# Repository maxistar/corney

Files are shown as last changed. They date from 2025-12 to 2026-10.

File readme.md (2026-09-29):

# Corney - Corney Chocoflan and Classical Corne keyboard

Project site and firmware guide: https://projects.maxistar.me/corney/

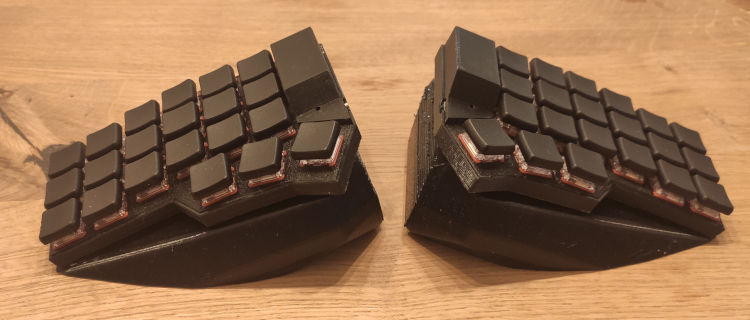
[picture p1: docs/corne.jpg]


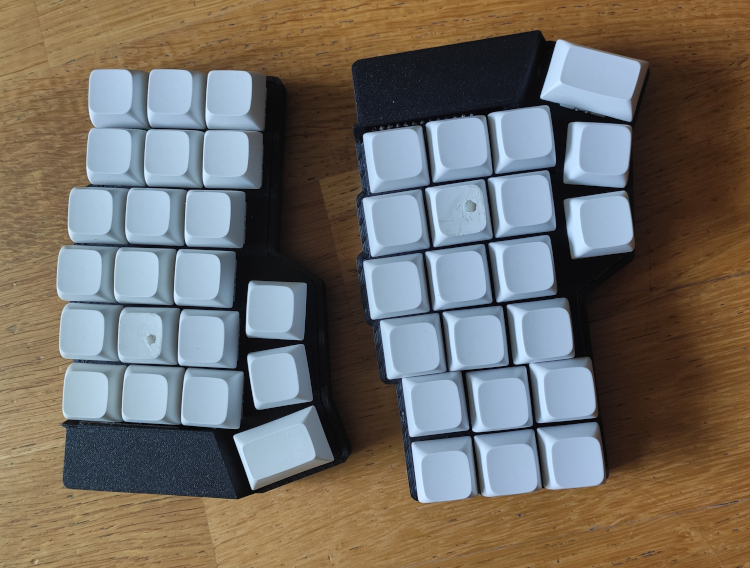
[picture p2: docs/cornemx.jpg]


- body remixed from this: https://www.printables.com/model/1020389-wireless-corne-chocoflan-minimal-keyboard-case

## Related Projects

- Dacty: https://github.com/maxistar/dacty

## Layout Helper

Use Keyboard Layout Helper to inspect and tune layers visually:
https://projects.maxistar.me/keyboard_helper/

## What's here

- `config/`: ZMK config for a split Corne on nice!nano (keymap, macros, Bluetooth bindings, west manifest).
- `body/`: printable/parametric case and plate models for the Chocoflan remix (scad, stl, step, 3mf).
- `build.yaml`: build matrix for CI (direct central, BLE halves, USB dongle, and reset firmware on `nice_nano_v2`).
- `website/`: static Astro project site and firmware selection guide. It can be built locally with
  `cd website && npm ci && npm run check && npm run build`; direct download links remain disabled
  until a versioned firmware release is physically accepted.
- `zephyr/module.yml`: declares the repo as a ZMK module, including the Corney shield root and
  the custom GATT features.
- `docs/gatt-layer-exposition.md`: UUIDs, data format, and build notes for the BLE layer
  characteristic.
- `docs/keyboard-helper-ble-v1.md`: implementation, security, queue, and build notes for the
  versioned Keyboard Helper event extension.
- `docs/dongle-oled-verification.md`: SSD1306 dongle wiring, resource delta, candidate hashes, and
  physical acceptance checklist.

## Clone

```bash
git clone https://github.com/maxistar/corney.git
cd corney
```

## Prerequisites

- Zephyr SDK and `west` already installed ([ZMK setup guide](https://zmk.dev/docs/development/setup))

## Build firmware (locally)

1. From the repo root, pull ZMK: `west init -l config && west update`.
2. Build the direct topology (outputs land in `build/<side>/zephyr/zmk.uf2`):
   - Left (enhanced): `west build -p -s zmk/app -d build/left -b nice_nano_v2 -- -DSHIELD=corney_left -DZMK_CONFIG=$PWD/config -DZMK_EXTRA_MODULES=$PWD -DCONFIG_ZMK_STUDIO=n -DCONFIG_ZMK_KEYBOARD_HELPER_EXTENSION=y`
   - Right: `west build -p -s zmk/app -d build/right -b nice_nano_v2 -- -DSHIELD=corney_right -DZMK_CONFIG=$PWD/config -DZMK_EXTRA_MODULES=$PWD`
3. Or build the dongle topology:
   - Left peripheral: `west build -p -s zmk/app -d build/left-peripheral -b nice_nano_v2 -- -DSHIELD=corney_left_peripheral -DZMK_CONFIG=$PWD/config -DZMK_EXTRA_MODULES=$PWD`
   - Right peripheral: use the same `corney_right` command and artifact as direct mode.
   - USB dongle: `west build -p -s zmk/app -d build/dongle -b nice_nano_v2 -- -DSHIELD=corney_dongle -DZMK_CONFIG=$PWD/config -DZMK_EXTRA_MODULES=$PWD -DCONFIG_ZMK_STUDIO=n -DCONFIG_ZMK_KEYBOARD_HELPER_EXTENSION=y`
4. Copy the corresponding UF2 to each nice!nano over USB bootloader.

`corney-left-enhanced` is the single supported left-central image for direct BLE operation. It
provides the ordinary keyboard HID behavior together with Keyboard Helper telemetry. Pair it with
the universal `corney-right` image, which supports right halves both with and without the physical
trackpad sensor.

The optional dongle topology uses `corney-left-peripheral` and the same `corney-right` image as two
BLE peripherals. `corney-usb-dongle` is their keyless central and sends keyboard and pointing HID
to the computer over USB. It drives a 128x64 SSD1306 status display over I2C and keeps the full
Keyboard Helper GATT service available over a separate encrypted BLE connection. Both host-facing
central images use the default name `Corney`.

ZMK Studio is intentionally disabled in the release firmware. The active layout is compiled from
`config/corney.keymap`; change that file and rebuild the left image to edit the layout. Previously
saved Studio overrides are not applied. The full Keyboard Helper event and diagnostics service
remains enabled.

## Build firmware with a custom Bluetooth name

The default Bluetooth device name is `Corney`. To override it, pass
`CONFIG_ZMK_KEYBOARD_NAME` when building a host-facing central.

Local build examples:

- Left (enhanced): `west build -p -s zmk/app -d build/left -b nice_nano_v2 -- -DSHIELD=corney_left -DZMK_CONFIG=$PWD/config -DZMK_EXTRA_MODULES=$PWD -DCONFIG_ZMK_STUDIO=n -DCONFIG_ZMK_KEYBOARD_HELPER_EXTENSION=y -DCONFIG_ZMK_KEYBOARD_NAME=\"CorneyMX\"`
- USB dongle: `west build -p -s zmk/app -d build/dongle -b nice_nano_v2 -- -DSHIELD=corney_dongle -DZMK_CONFIG=$PWD/config -DZMK_EXTRA_MODULES=$PWD -DCONFIG_ZMK_STUDIO=n -DCONFIG_ZMK_KEYBOARD_HELPER_EXTENSION=y -DCONFIG_ZMK_KEYBOARD_NAME=\"CorneyMX\"`
- Right: `west build -p -s zmk/app -d build/right -b nice_nano_v2 -- -DSHIELD=corney_right -DZMK_CONFIG=$PWD/config -DZMK_EXTRA_MODULES=$PWD`

Do not apply the custom name override to either peripheral image. Only the active central is
host-facing.

## Cirque trackpad

Both halves support an optional Cirque Pinnacle trackpad over their own Pro Micro I2C pins. Each
sensor uses address `0x2a`, does not connect its data-ready (`DR`) signal, and replaces rather than
shares the former OLED position. The same `corney-left-enhanced` and `corney-right` images support
four physical arrangements: no sensor, left only, right only, or one sensor on each half.

Because DR is absent, each controller with an installed sensor reads its status every 8 ms while
active. The left central consumes its local sensor directly. The right half forwards relative
movement, primary tap, and wheel packets over ZMK input-split to a separate central proxy listener.
Both paths produce ordinary USB or BLE HID mouse reports; Keyboard Helper remains central-owned and
does not carry pointer packets.

In dongle mode, both sensors are remote. The right endpoint retains input-split register `0`; the
left peripheral uses register `1`. The dongle has matching proxy listeners and no physical sensor
or matrix of its own. Button state is tracked per proxy. Because pinned ZMK v0.3.0 does not expose
the disconnected split connection's input-split identity, any split disconnect conservatively
clears retained remote button state; later events from a still-connected half continue normally.

The original left installation uses `invert-x`. The accepted right installation is rotated 180
degrees relative to its first prototype and uses `invert-y` without `invert-x`. These settings make
physical finger direction match cursor direction on each assembled half.

If either image boots without its optional sensor, initialization fails once and periodic polling
is not started on that controller. Matrix scanning, split operation, and an installed sensor on the
other half remain independent. The pinned ZMK baseline does not release input-split buttons
automatically on disconnect, so the left firmware tracks only right-proxy button state and performs
a bounded safety release when that split connection disappears. Local left buttons are not part of
that disconnect state.

Continuous polling costs additional battery power on every sensor-equipped half. During system
suspend the corresponding polling work stops; trackpad touch alone cannot wake that controller
without DR. Wake the left sensor with a left-local key and the right sensor with a right-local key or
another wake source on the same controller. The right pointing path also waits for split reconnect.

Movement, scrolling, and ordinary non-overlapping taps may be used from either sensor. The pinned
ZMK input listener does not source-count a simultaneous hold of the same mouse button from two
sensors, so that specific dual-button gesture is unsupported.

The explicitly named Choc printable entry points are
`body/Choc_Version/right_touchpad_body.scad` and
`body/Choc_Version/right_touchpad_cover.scad`; use
`body/Choc_Version/right_touchpad_assembly.scad` to inspect controller, reset, sensor, and wiring
clearances. Hardware acceptance for this topology is tracked in
`docs/right-peripheral-trackpad-verification.md`.

## USB dongle OLED

The `corney-usb-dongle` firmware selects one four-wire 128x64 SSD1306 module at I2C address `0x3c`
and displays a hybrid status screen. It preserves ZMK's standard output indicator at the upper
left, local dongle battery indicator at the upper right, and active layer at the lower left. One
compact row below the local battery shows both split-peripheral levels, for example `78% 56%`.

The two remote values follow persistent ZMK split-slot order but deliberately have no slot numbers
or left/right labels. Resetting bonds can reverse their order without changing the meaning of the
pair. An unavailable, not-yet-seen, or disconnected value is shown as `--`; pinned ZMK v0.3.0 also
uses zero as its disconnect sentinel, so a genuine remote `0%` is indistinguishable and is likewise
shown as unavailable. The standard dongle battery widget's power symbol reports USB presence; it
does not establish that an optional dongle cell is charging.

Wire the display only to the dedicated dongle nice!nano v2:

| SSD1306 pin | nice!nano v2 / Pro Micro pin |
| --- | --- |
| `VCC` | `3V3` |
| `GND` | `GND` |
| `SDA` | `D2` / `P0.17` |
| `SCL` | `D3` / `P0.20` |

Use a 3.3 V-compatible module; do not power an unknown panel from `RAW` or 5 V. The firmware expects
address `0x3c`, 128x64 geometry, and the orientation used by the tested module. The screen normally
blanks when ZMK enters idle and resumes after keyboard activity. The left and right halves do not
contain this OLED node—their separate I2C buses remain available for optional Cirque sensors.

Only the dongle needs to be reflashed for this display change. If the hybrid screen prevents normal
dongle operation, reflash
`.artifacts/show-corney-battery-levels-on-dongle/corney-usb-dongle.uf2`; the two peripheral images
and their split bonds do not otherwise change. Build and physical acceptance evidence is recorded
in `docs/dongle-hybrid-status-screen-verification.md`.

## CI/CD

GitHub Actions is the primary CI/CD pipeline. It runs portable protocol/metadata tests, native ZMK
integration tests, and builds `corney-left-enhanced`, `corney-left-peripheral`, `corney-right`,
`corney-usb-dongle`, and `settings-reset` firmware artifacts. A manual workflow run can override
the Bluetooth name for either central image only.

The GitLab CI configuration is retained as an equivalent alternative for a future GitLab mirror.
Local Bluetooth name overrides remain a CMake option so the right/peripheral image cannot
accidentally receive a host-facing name.

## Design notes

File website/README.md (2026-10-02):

# Corney website

Static Astro site for `https://projects.maxistar.me/corney/`.

```sh
npm ci
npm run check
npm run build
npm run dev
```

`src/data/firmware.js` is the public firmware source of truth. The checked-in record stays
`published: false` until a versioned GitHub Release is physically accepted and its five UF2 hashes
have been verified. Source code changes and temporary CI artifacts do not activate download links.

The production build validates routes, base paths, topology mappings, release claims and image
metadata. Public WebP photographs are sanitized derivatives of the repository's `docs/` originals.

## 3D models

The STL files served on the Models page are not committed here. `scripts/models-manifest.mjs` lists
each published `models/<group>/<file>.stl` and the file under `../body/` it comes from, and
`scripts/sync-models.mjs` copies them into the git-ignored `public/models/`. The sync runs
automatically before `npm run dev`, `check` and `build`; run `npm run sync-models` to do it by hand.
It fails on a missing source, a duplicate target, or an unlisted STL in `public/models/`. To publish a
new model, add it to the manifest and to `src/pages/models.astro`; a test checks that both agree. The
website workflow also runs when an STL under `body/` changes.

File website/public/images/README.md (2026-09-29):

# Corney website images

`corney-choc.webp` derives from `../../../docs/corne.jpg`; `corney-mx.webp` derives from
`../../../docs/cornemx.jpg`. Both source photographs belong to this repository. Public variants
were converted with ImageMagick `-auto-orient -strip -resize '1200x900>' -quality 82`, removing EXIF,
including location and camera information.

The alt descriptions live in `src/data/project.js`. There is currently no public photograph of the
dongle OLED or an installed trackpad; the site uses text and diagrams for those features.

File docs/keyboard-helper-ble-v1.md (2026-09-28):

# Keyboard Helper BLE extension v1

Corney's central (`corney_left`) firmware implements version 1.0 of the Keyboard Helper BLE
contract documented by the umbrella repository in `docs/zmk-ble-keyboard-contract-v1.md`. The
right/peripheral firmware preserves ordinary ZMK split position forwarding and never advertises
the host-facing service.

## Build modes

`CONFIG_ZMK_GATT_LAYER_EXPOSITION=y` keeps the legacy four-byte layer register available.
`CONFIG_ZMK_KEYBOARD_HELPER_EXTENSION=y` adds the capabilities and encrypted event stream. The
extension defaults off in Kconfig, while the supported `corney-left-enhanced` release artifact
enables it explicitly. The switches remain available for focused tests and local experiments, but
disabled and partial-extension configurations are not published release variants.

Optional capability switches are:

- `CONFIG_ZMK_KEYBOARD_HELPER_KEY_EVENTS`
- `CONFIG_ZMK_KEYBOARD_HELPER_COMBO_EVENTS`
- `CONFIG_ZMK_KEYBOARD_HELPER_LAYER_EVENTS`
- `CONFIG_ZMK_KEYBOARD_HELPER_DIAGNOSTICS`

The capabilities value is derived from these compiled options. Disabling one source clears only
its bit. Capability bit 3 and event type `0x04` are reserved and never emitted. Standard ZMK
Battery Service is the sole battery source in the maintained enhanced mode. Peripheral battery
fetching remains disabled and right-half battery support is deferred.

## Event capture

- Physical key events subscribe directly to central-observed `zmk_position_state_changed` and
  retain global positions `0..41` from both halves.
- Seven combo behaviors use a Corney wrapper that publishes stable combo ID and participants,
  then invokes the original ZMK binding unchanged.
- Legacy and enhanced layer reporting share the same authoritative cached highest layer.
- The custom stream contains no HID usage, keycode, Unicode, resolved behavior, or text.

`layout_corney.json` and `corney_macros.dtsi` carry the same combo IDs and positions. Run
`tests/run-host-tests.sh` to validate the mapping and the exact version 1 frame examples. Run
`tests/run-zmk-integration-tests.sh` to verify raw combo-participating positions, wrapper
press/release delegation, overlap resolution, non-text behavior, and absence of duplicate resolved
events in ZMK's native test runner.

## Queue and loss behavior

Event producers allocate one global sequence and perform a bounded, non-blocking append into
16-entry retained history. Each subscriber has its own cursor and retry state while notification
runs later in work context. A transient `-ENOMEM` or `-EAGAIN` result is retried no more than three
times, 10 ms apart, for the affected subscriber without delaying other ready subscribers.
Permanent failures, an exhausted retry budget, and history overwritten before a slow subscriber
consumes it produce a gap only in that subscriber's observed stream. Shared retention overflow
also schedules diagnostic code 1 when capacity becomes available.

## Concurrent subscribers and security

Capabilities remain readable before encryption. Enabling the event CCC requires an encrypted
connection. Every eligible connection receives an independent subscriber slot while configured
Bluetooth capacity remains available. Corney configures six simultaneous connections: one for
the right split peripheral and five host profiles, so at least two encrypted event subscribers
can coexist. `BT_ATT_ERR_INSUFFICIENT_RESOURCES` is reserved for actual subscriber/connection
capacity exhaustion and never transfers or cancels an existing subscription.

Telemetry subscription is independent of the active ZMK HID profile. Every subscriber receives a
targeted authoritative layer snapshot marked `STREAM_START | SNAPSHOT` before its future live
events. A subscriber joining, leaving, slowing down, or reconnecting does not reset or purge any
other subscriber's stream.

Firmware flashed before concurrent subscriber support is a development-only build and must be
reflashed. Protocol 1.0 UUIDs, capability bytes, and event frame layouts are unchanged; there is
no single-owner compatibility mode or version branch.

## Local verification

Run the portable tests:

```sh
tests/run-host-tests.sh
```

Build the enhanced central:

```sh
west build -p always -s zmk/app -d build/enhanced-left -b nice_nano_v2 -- \
  -DZMK_CONFIG="$PWD/config" \
  -DZMK_EXTRA_MODULES="$PWD" \
  -DSHIELD=corney_left \
  -DCONFIG_ZMK_KEYBOARD_HELPER_EXTENSION=y
```

Build `corney_right` without the extension override. A GATT database change can require clearing
old bonds or flashing the `settings_reset` image before pairing again.

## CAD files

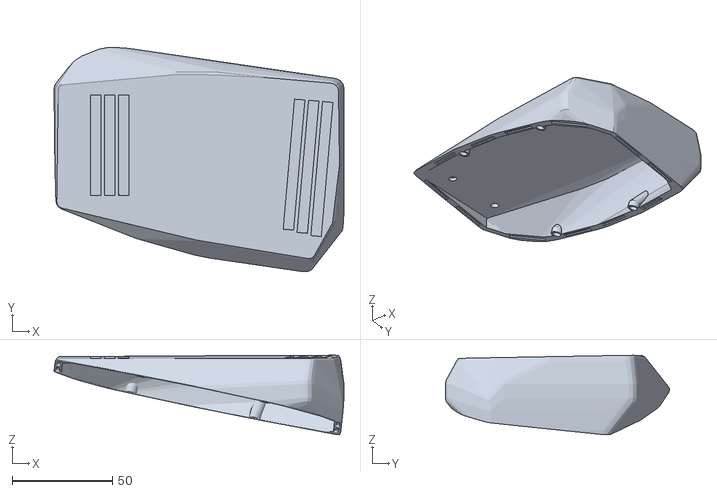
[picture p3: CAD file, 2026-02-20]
body/board_case.stl
144.3 x 111.7 x 39.6

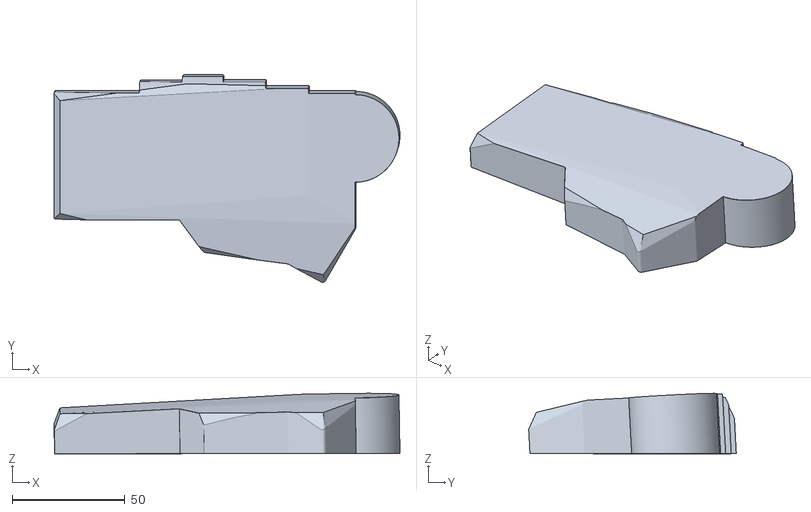
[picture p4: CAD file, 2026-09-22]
body/Choc_Version/internalshape.stl
153.6 x 92.2 x 26.9

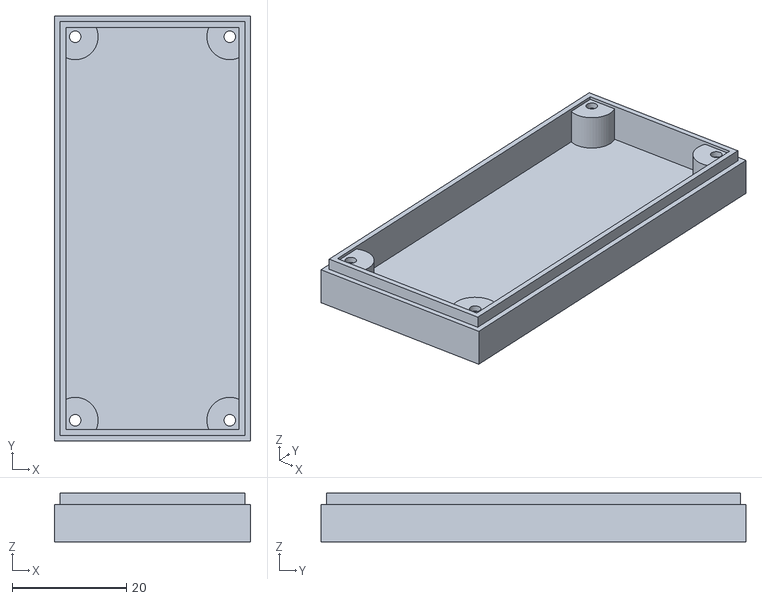
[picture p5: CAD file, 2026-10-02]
body/dongle/dongle_breadboard_bottom.stl
34.2 x 74.2 x 8.50

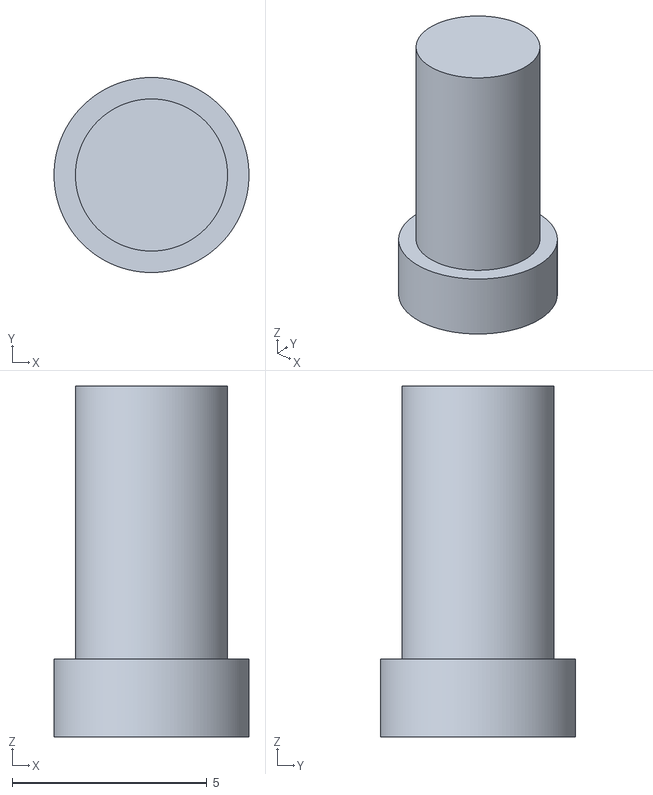
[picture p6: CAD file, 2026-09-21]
body/Choc_Version/reset_button_right.stl
5.00 x 5.00 x 9.00

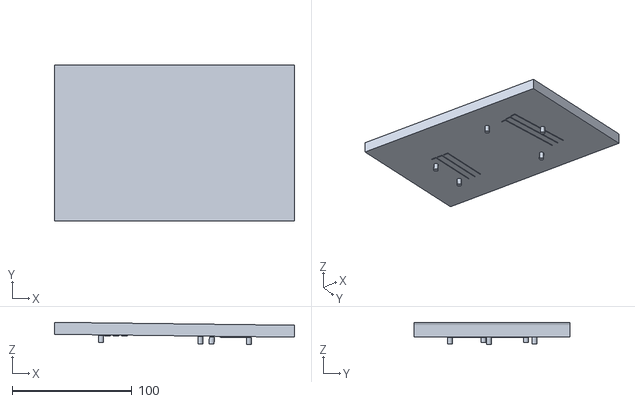
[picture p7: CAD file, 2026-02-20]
body/corne_shape_with_stands.stl
200.1 x 130.0 x 18.7

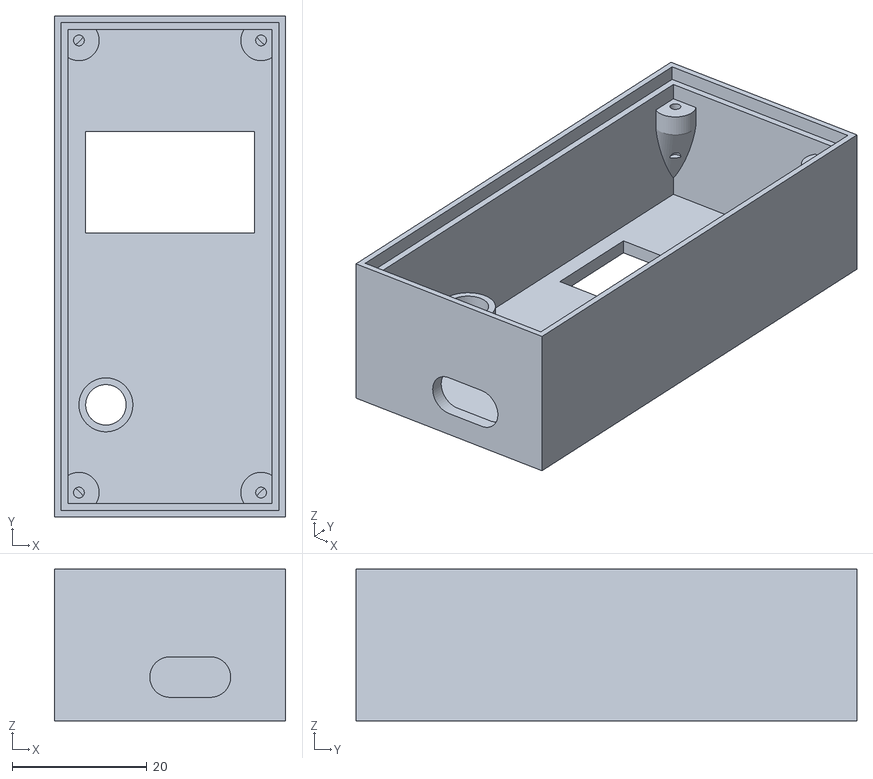
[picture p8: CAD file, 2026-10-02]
body/dongle/dongle_breadboard_upper.stl
34.2 x 74.2 x 22.5

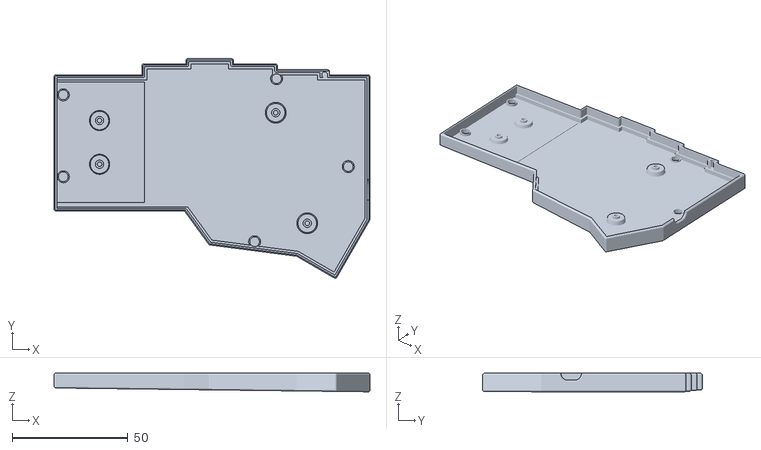
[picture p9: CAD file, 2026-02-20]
body/body_with_stands.stl
136.6 x 94.9 x 8.06

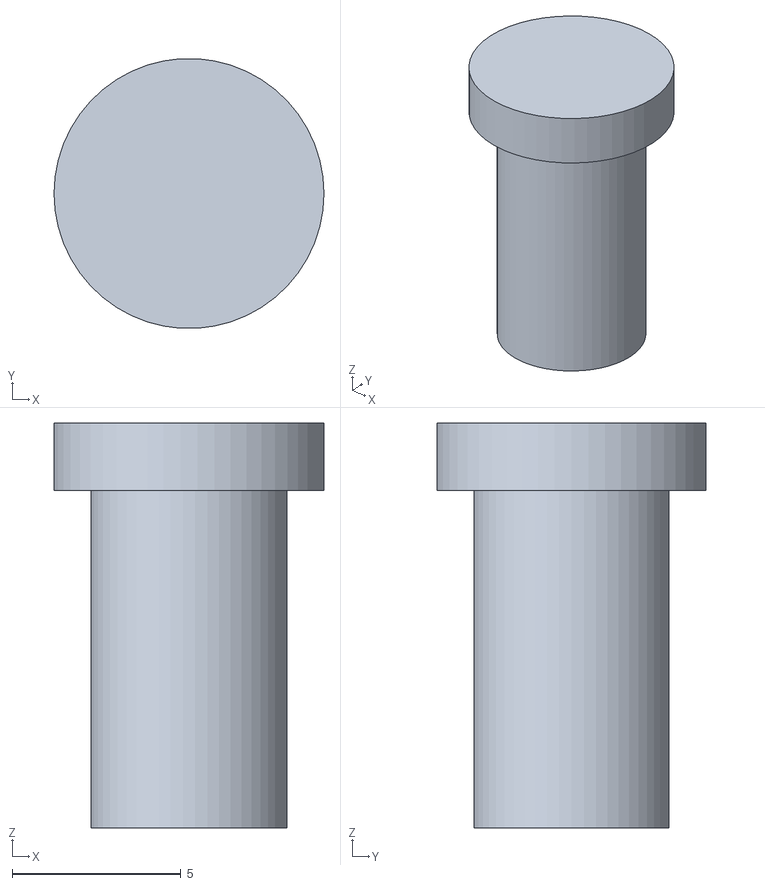
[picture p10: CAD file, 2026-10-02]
body/dongle/dongle_breadboard_button.stl
8.00 x 7.98 x 12.0

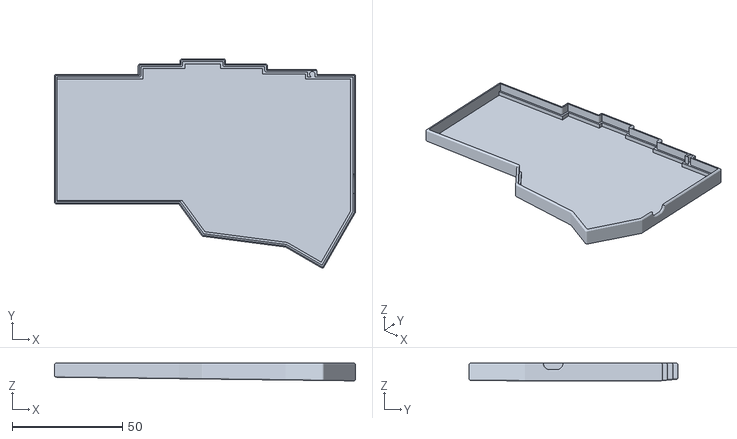
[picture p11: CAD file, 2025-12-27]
body/corne_chocoflan_basic.stl
136.6 x 94.9 x 8.06

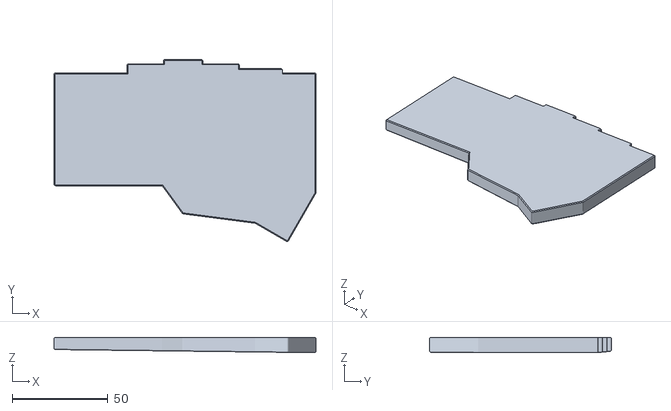
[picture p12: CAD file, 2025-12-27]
body/corne_shape.stl
136.6 x 94.9 x 8.06

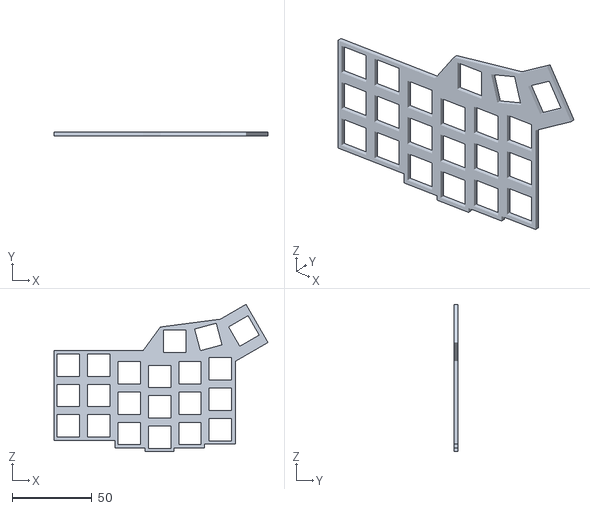
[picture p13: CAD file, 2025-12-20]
body/tbenen-plate.stl
133.8 x 2.20 x 92.2

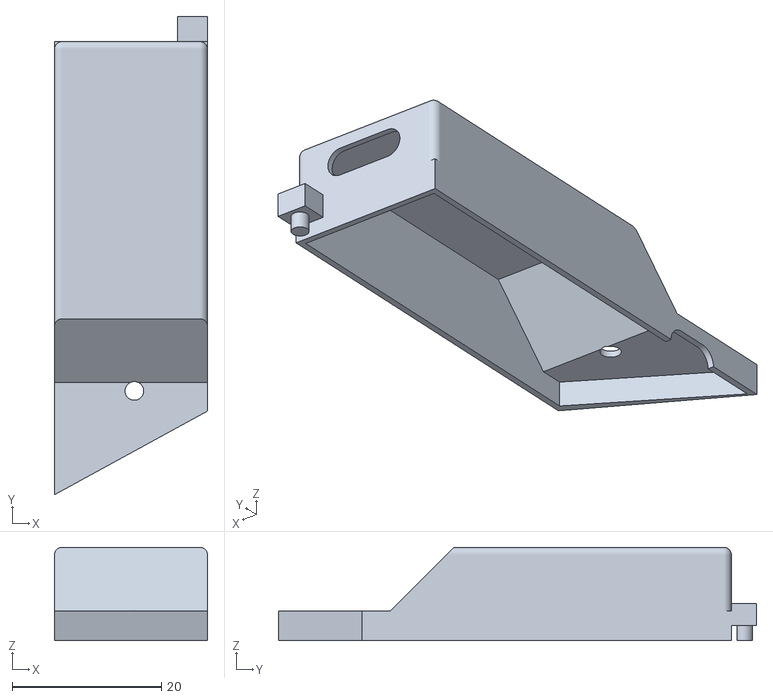
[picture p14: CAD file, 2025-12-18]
body/board_cover.stl
20.5 x 64.1 x 12.5

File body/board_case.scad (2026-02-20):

// case
/**
features todo: 
- [x] magnetic latch
- [x] placing keyboad on top of case as tilted support
- [x] magnetic fixation of the keyboard
- [x] additional pads fixation for the keyboard
- [x] rubber perimeter for better stability
- [ ] make maglet holders 3dprint friendly

*/

cut_angle = [-6, 13, 0];
magnet_radius = 4 / 2 + 0.1;
holder_thickness = 0.8;

module column3() {
  translate([32, 120, 14])
    cube([18, 18, 5], center=true);

  translate([32, 120 - 19, 14])
    cube([18, 18, 5], center=true);

  translate([32, 120 - 19 * 2, 14])
    cube([18, 18, 5], center=true);
}

module corne() {

  translate([17, 143, -8.5])
    import("body_with_stands.stl");

  translate([0, 136, -84])
    rotate([90, 0, 0])
      import("tbenen-plate.stl");

  translate([157, 129, 6])
    scale([-1, 1, 1])
      import("board_cover.stl");

  column3();

  translate([19, 0, 0])
    column3();

  translate([19 * 2, 3, 0])
    column3();

  translate([19 * 3, 6, 0])
    column3();

  translate([19 * 4, 3, 0])
    column3();

  translate([19 * 5, 0, 0])
    column3();

  translate([99, 66, 14])
    cube([18, 18, 5], center=true);

  translate([120, 63, 14])
    rotate([0, 0, -15])
      cube([18, 18, 5], center=true);

  translate([142, 60, 14])
    rotate([0, 0, -30])
      cube([18, 18, 5], center=true);
}

//corne();

module corne_centered() {
  translate([-90, -95, 0.1])
    corne();
}

module base_centered() {
  translate([-90, -95, 2])
    hull() {
      import("corne-chocoflan-case.stl");
    }
}

module cut_centered() {
  rotate([1, -1.0, 0])
    translate([-70, 48, -8.35])
      //hull() {
      import("corne_shape_with_stands.stl");
  //} 
}

module two_cornes() {
  corne_centered();

  rotate([0, 180, 0])
    scale([1, -1, 1])
      corne_centered();
}

module outline() {
  hull() {
    two_cornes();
  }
}

//two_cornes();

module shell() {
  difference() {
    minkowski() {
      outline();
      sphere(r=4.2);
    }

    minkowski() {
      outline();
      sphere(r=0.5);
    }
  }
  double_magnet_plane_half(magnet_radius + holder_thickness, 3);
}

module one_half() {

  difference() {
    shell();

    rotate(cut_angle)
      translate([0, 0, -50])
        cube([400, 400, 100], center=true);

    translate([5, 0, 20])
      cut_centered();

    double_angled_cuts();

    double_magnet_plane(magnet_radius, 2, 0.1);
  }

  intersection() {
    minkowski() {
      outline();
      sphere(r=4);
    }
    rotate(cut_angle) {
      print_helpers();
    }
  }
}

module print_helpers() {
  translate([30, 35.6, 2.7])
    hull() {
      cylinder(h=0.5, r=magnet_radius + holder_thickness, $fn=50);

      translate([3, 15, 20])
        cylinder(h=0.5, r=magnet_radius + holder_thickness, $fn=50);
    }

  translate([-30, -35.6, 2.7])
    hull() {
      cylinder(h=0.5, r=magnet_radius + holder_thickness, $fn=50);

      translate([0, -10, 10])
        cylinder(h=0.5, r=magnet_radius + holder_thickness, $fn=50);
    }

  translate([-33, 50, 2.7])
    hull() {
      cylinder(h=0.5, r=magnet_radius + holder_thickness, $fn=50);

      translate([0, 5, 10])
        cylinder(h=0.5, r=magnet_radius + holder_thickness, $fn=50);
    }

  translate([33, -50, 2.7])
    hull() {
      cylinder(h=0.5, r=magnet_radius + holder_thickness, $fn=50);

      translate([0, -5, 10])
        cylinder(h=0.5, r=magnet_radius + holder_thickness, $fn=50);
    }
}

one_half();

/*
translate([0, 0, -30])
  rotate([0, 180, 0])
    scale([1, -1, 1])
      one_half();
*/

module rubber_cuts() {
  translate([10, 44.2, 0])
    rotate([0, 0, -16])
      cube([20, 1.8, 1.8], center=true);

  translate([-19, 50.5, 0])
    rotate([0, 0, -8])
      cube([20, 1.8, 1.8], center=true);

  translate([-52.5, 49.5, 0])
    rotate([0, 0, 22.9])
      cube([20, 1.8, 1.8], center=true);

  translate([44, 33.5, 0])
    rotate([0, 0, -22])
      cube([20, 1.8, 1.8], center=true);

  translate([71, 6, 0])
    rotate([0, 0, -88])
      cube([20, 1.8, 1.8], center=true);

  translate([71, -22, 0])
    rotate([0, 0, -91])
      cube([20, 1.8, 1.8], center=true);
}

module angled_cuts() {
  rotate(cut_angle)
    rubber_cuts();
}

module double_angled_cuts() {
  angled_cuts();

  rotate([0, 180, 0])
    scale([1, -1, 1])
      angled_cuts();
}

module magnets_plane(radius, height, voffset) {

  translate([33, -49.9, voffset])
    cylinder(h=height * 2 + voffset * 2, r=radius, $fn=50, center=true);

  translate([30, 35.6, voffset])
    cylinder(h=height * 2 + voffset * 2, r=radius, $fn=50, center=true);
}

module angled_magnet_plane(radius, height, voffset) {
  rotate(cut_angle)
    magnets_plane(radius, height, voffset);
}

module double_magnet_plane(radius, height, voffset = 0) {
  angled_magnet_plane(radius, height, voffset);

  rotate([0, 180, 0])
    scale([1, -1, 1])
      angled_magnet_plane(radius, height, voffset);
}

module double_magnet_plane_half(radius, height, voffset = 0) {
  difference() {
    double_magnet_plane(radius=radius, height=height, voffset=voffset);

    rotate(cut_angle)
      translate([0, 0, -50])
        cube([400, 400, 100], center=true);
  }
}

module test_magnet() {
  difference() {
    cylinder(h=3, r=magnet_radius + holder_thickness, $fn=50);
    translate([0, 0, -0.1])
      cylinder(h=2 + 0.1, r=magnet_radius, $fn=50);
  }
}

//test_magnet();
//difference() {

//}

//double_angled_cuts();

//translate([5, 0, 20])
//  cut_centered();

//corne_centered();

//translate([0, 0, -40])
//  rotate([0, 180, 0])
//    scale([1, -1, 1])
//      corne_centered();

/*
difference() {

  translate([0, 0, -40])
    intersection() {
      shell();

      rotate([0, 20, 0])
        translate([0, 0, -50])
          cube([400, 400, 100], center=true);
    }

  translate([-15, 0, -60])
    rotate([0, 180, 0])
      scale([1, -1, 1])
        cut_centered(); 
}

*/
//import("corne_shape.stl");

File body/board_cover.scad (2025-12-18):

/**

- [x] sitting pins
- [ ] reset button cut
- [x] usb-c cut
- [x] power button cut
- [x] board space
- [x] bottom plate that fits into horizontal cut

*/

$fn = 50;

cover_width = 20.5;
cover_length_1 = 60.71;
cover_length_2 = 49.5;

cover_height = 12.5;
cover_height_min = 4;

wall_thickness = 0.8;
sittin_pin_radius = 2.5 / 2;

round_radius = 1.0;

module outer_shape_old() {
  linear_extrude(height=cover_height_min) {
    polygon([[0, 0], [0, -cover_length_1], [cover_width, -cover_length_2], [cover_width, 0]]);
  }

  difference() {
    linear_extrude(height=cover_height) {
      polygon([[0, 0], [0, -cover_length_1], [cover_width, -cover_length_2], [cover_width, 0]]);
    }

    translate([0, -60, 25])
      rotate([45, 0, 0])
        cube([100, 100, 50], center=true);
  }
}

module outer_shape() {

  wall_radius_bottom = 0;
  wall_radius_top = round_radius;

  linear_extrude(height=cover_height_min) {
    polygon([[wall_radius_bottom, -wall_radius_bottom], [wall_radius_bottom, wall_radius_bottom - cover_length_1], [cover_width - wall_radius_bottom, wall_radius_bottom - cover_length_2], [cover_width - wall_radius_bottom, -wall_radius_bottom]]);
  }

  difference() {
    minkowski() {
      linear_extrude(height=cover_height - wall_radius_top) {
        polygon([[wall_radius_top, -wall_radius_top], [wall_radius_top, wall_radius_top - cover_length_1], [cover_width - wall_radius_top, wall_radius_top - cover_length_2], [cover_width - wall_radius_top, -wall_radius_top]]);
      }
      sphere(r=wall_radius_top);
    }

    translate([0, -60, 25])
      rotate([45, 0, 0])
        cube([100, 100, 50], center=true);

    translate([0, 0, -50])
      cube([200, 200, 100], center=true);
  }
}

module inner_shape() {
  difference() {
    translate([0, 0, -wall_thickness]) {
      linear_extrude(height=cover_height) {
        polygon([[wall_thickness, -wall_thickness], [wall_thickness, wall_thickness - cover_length_1], [cover_width - wall_thickness, wall_thickness - cover_length_2], [cover_width - wall_thickness, -wall_thickness]]);
      }
    }

    translate([0, -60, 25 - wall_thickness])
      rotate([45, 0, 0])
        cube([100, 100, 50], center=true);
  }

  translate([0, 0, -wall_thickness]) {
    linear_extrude(height=cover_height_min) {
      polygon([[wall_thickness, -wall_thickness], [wall_thickness, wall_thickness - cover_length_1], [cover_width - wall_thickness, wall_thickness - cover_length_2], [cover_width - wall_thickness, -wall_thickness]]);
    }
  }
}

module cuts() {

  // Power button cut
  translate([-5, -50.5, 0]) {
    rotate([0, 90, 0]) {
      hull() {
        cylinder(h=9, r=2.0, center=false);
        translate([0, 4, 0])
          cylinder(h=9, r=2.0, center=false);
      }
    }
  }

  // USB-C cut
  translate([14, -6, 8.6]) {
    rotate([0, 90, 90]) {
      hull() {
        cylinder(h=10, r=1.8, center=false);
        translate([0, 7, 0])
          cylinder(h=9, r=1.8, center=false);
      }
    }
  }

  translate([cover_width - 9.8, -cover_length_2 + 2.7, wall_thickness])
    cylinder(h=cover_height_min, r=sittin_pin_radius, center=false);
}

difference() {
  outer_shape();
  inner_shape();
  cuts();
}
/*
translate([3.6, -cover_length_1 + 5.7, -wall_thickness])
  cylinder(h=cover_height_min, r=sittin_pin_radius, center=false);

translate([cover_width - 4.5, -cover_length_2 + 3, -wall_thickness])
  cylinder(h=cover_height_min, r=sittin_pin_radius, center=false);
*/
translate([cover_width - 2.0, +1.8, /*-wall_thickness*/ 0])
  cylinder(h=cover_height_min, r=sittin_pin_radius - 0.2, center=false);

translate([16.5, 0, 2]) {
  cube([4, 3.4, 3]);
}

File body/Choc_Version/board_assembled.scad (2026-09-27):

use <body_thin.scad>
use <board_cover.scad>
use <reset_button_right.scad>
use <_buttons_low_profile.scad>
use <_auxiliary.scad>


module panelbuttons(fullheight = false, simplified = false) {
  if (simplified) {
    body_simplified();
  } else {
    body();
    panel();
  }


  buttons();

  /*
  translate([58, 13, 20]) {
    nice_nano_placeholder();
  }
  */

  if (simplified) {
    translate([0, 0, 15.5]) {
      cover_simplified();
      resetButtonSmall();
    }
  } else {
    translate([0, 0, 15.5]) {
      cover();
      resetButtonSmall();
    }
  }

  
}

module panelbuttonsmoved(fullheight = false, simplified=false) {
  translate([0, 0, -4]) {
    panelbuttons(fullheight=fullheight, simplified = simplified);
  }
}

//panel();
panelbuttonsmoved(simplified = true);

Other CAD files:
body/ImprovedCorne.FCStd
body/corne-chocoflan-case.step
body/Choc_Version/board_assembled_touchpad.scad
body/Choc_Version/_auxiliary.scad
body/Choc_Version/_buttons_low_profile.scad
body/Choc_Version/board_case.scad
body/Choc_Version/board_cover.scad
body/Choc_Version/board_cover_touchpad.scad
body/Choc_Version/body_thin.scad
body/Choc_Version/body_thin_touchpad.scad
body/Choc_Version/face_panel.scad
body/Choc_Version/reset_button.scad
body/Choc_Version/reset_button_right.scad
body/Choc_Version/right_touchpad_assembly.scad
body/Choc_Version/right_touchpad_body.scad
body/Choc_Version/right_touchpad_cover.scad
body/Choc_Version/travel_case_side_by_side.scad
body/Choc_Version/twokeyboards.scad
body/Choc_Version/twokeyboards_side_by_side.scad
body/MX_Version/Outline.scad
body/MX_Version/Outline_thin.scad
body/MX_Version/board_assembled.scad
body/MX_Version/board_case.scad
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

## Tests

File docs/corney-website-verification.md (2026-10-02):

# Corney website verification

# Website status

The public site is deployed at https://projects.maxistar.me/corney/ and the visual presentation was
accepted by the project owner. Home, Firmware, Build and Guide are available under `/corney/`. It uses the
two existing assembly photographs as sanitized WebP assets and keeps firmware downloads unpublished
until a versioned, physically accepted compatibility set is selected.

## Local checks

- `website/npm run check`: Astro diagnostics have 0 errors, 0 warnings and 0 hints; firmware data
  tests pass.
- `website/npm run build`: four static routes build; the post-build validator passes route, asset,
  base-path, topology, release-state, image-alt and WebP metadata checks.
- `website/npm audit --audit-level=low`: 0 vulnerabilities after upgrading to Astro 7 and using
  self-hosted fonts.
- `tests/run-host-tests.sh`: existing Corney host checks and release packaging tests pass.
- The project owner confirmed that the GitHub Actions tests pass after the host-test fix.
- A local package smoke test using the five previously accepted UF2 files and their generated
  Kconfig outputs produced a checksummed ZIP with exactly five images plus `SHA256SUMS`.
- In a browser, all four routes had no horizontal overflow or broken images at 320 and 1440 CSS
  pixels. The first Tab focuses the visible skip link. No remote page resources loaded; primary
  content rendered from static HTML. The unpublished firmware page exposed no release asset links.
- Primary repo, Choc and MX source, keymap, contributor documents and Keyboard Helper URLs returned
  HTTP 200 during local verification.
- Representative text contrast ratios: muted copy 9.55:1, accent on page background 15.10:1,
  warning text 10.74:1 and button text 14.60:1.
- The deployed Home, Firmware, Build and Guide routes were smoke-tested in a browser at 320 and
  1440 CSS pixels: no page-level horizontal overflow, broken images, missing image alternatives,
  or internal links escaping `/corney/` were found.

## Prototype dongle case

The Models page has a "USB dongle case (prototype)" set with three STL files copied from
`body/dongle/` (source last changed in `e1ed106`, byte-identical at copy time): bottom shell, upper
shell and reset button. The Build page has a prototype block (30 x 70 mm breadboard design basis,
adjustable OpenSCAD parameters, screen cut-out still being refined) and the Guide dongle section links
to it as optional. The Home page is unchanged.

- `website/npm run check` and `npm run build`: 0 errors, 4 data tests pass, the post-build validator
  passes with five routes.
- Local preview: the dongle set loads its STL (HTTP 200), the viewer renders the shell with no console
  errors, and the Build page has no horizontal overflow at 320 CSS pixels.

## Models built from sources

The 3D models are no longer committed under `website/public/models/`. `website/scripts/models-manifest.mjs`
maps each published model to its file in `body/`, and `scripts/sync-models.mjs` copies them before
`dev`, `check` and `build`; the output directory is git-ignored. The website workflow also runs when an
STL under `body/` changes.

- Before untracking, the generated directory was byte-identical to the 16 committed copies and the 3
  untracked dongle copies.
- From an empty `public/models/`, `npm run check` (8 tests pass) and `npm run build` pass, and the
  resulting `dist/` is identical to the previous build output, including all 19 STL files.
- Fault injection: an unlisted STL, a missing source (the build aborts before Astro runs) and a
  duplicate target each fail with a message naming the entry; the mapping was restored afterwards.

## Firmware release still pending

- Choose the first release version and accepted source revision.
- Create the tagged candidate, verify its published assets, and perform physical acceptance of both
  firmware topologies and settings reset.
- Update the checked-in release record only after the candidate is physically accepted.

The website deployment does not constitute acceptance or publication of a firmware release.

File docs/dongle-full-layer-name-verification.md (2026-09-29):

# Corney Dongle Full Layer Name Verification

Date: 2026-09-29

## Change

The dongle's custom status screen now reads the active layer's complete ZMK display name and draws
it beside a stationary keyboard symbol in the bottom row. The label uses all 112 pixels to the
right of the 14-pixel symbol and 2-pixel gap. LVGL circular scrolling is enabled on that label; text
that fits the row stays static, while longer names move through the available window at 20 pixels
per second. The configured LVGL default is 49 pixels per second, so the new rate is about 2.45
times slower (the nearest whole-pixel speed to exactly 2.5 times slower).

The existing output, local dongle battery, and two remote battery indicators retain their positions
and data paths. The implementation replaces only the dongle screen's stock layer widget, whose
14-byte formatting buffer truncated names before LVGL received them.

## Automated verification

- [x] Corney host tests pass, including source/layout checks for the ZMK active-layer API, layer
  event subscription, full-width name label, circular overflow mode, fixed keyboard symbol,
  reduced scroll speed, and dongle-only source selection.
- [x] Generated configuration and topology checks pass for all five Corney release targets.
- [x] Only `corney-usb-dongle` selects the custom screen; its stock layer widget is disabled. The
  other four retained release UF2 hashes are unchanged from the accepted battery-screen build.
- [x] The dongle target builds on pinned ZMK v0.3.0.

## Resource usage

| Dongle image | FLASH | RAM | UF2 size |
| --- | ---: | ---: | ---: |
| Accepted battery-screen image | 328,564 B | 68,436 B | 657,408 B |
| Full layer name candidate at 20 px/s | 345,800 B | 68,596 B | 691,712 B |
| Change | +17,236 B | +160 B | +34,304 B |

The candidate uses 42.64% of the 792 KiB application flash region and 26.17% of the 256 KiB RAM
region.

## Candidate artifact

The candidate and its generated configuration and devicetree are retained under
`.artifacts/show-full-layer-name-on-corney-dongle/`.

| Artifact | Size | SHA-256 |
| --- | ---: | --- |
| `corney-usb-dongle.uf2` | 691712 bytes | `37c69459b891b583ffd7e9dd11c3bde6a99d83de31c606c4ed522dafdb3a64a9` |

Rollback to the accepted battery-screen-only image at
`.artifacts/show-corney-battery-levels-on-dongle/corney-usb-dongle.uf2` (657408 bytes,
SHA-256 `675c8a22f8a7ce96112b784710e4675035262cc9e60d813c6a68d91fafdf674a`). Only the dongle needs
flashing; no half firmware or BLE bond change is expected.

## Physical acceptance

- [x] Confirmed a short name remains stationary and a long name, such as `MAC: Characters and
  Navigation Russian`, scrolls fully and legibly next to the keyboard symbol.
- [x] Confirmed the 20 px/s scroll speed is comfortable; layer changes, output and battery rows,
  display idle blanking/wake, and existing
  dongle typing, pointing, BLE reconnect, and Keyboard Helper behavior remain usable.

Physical acceptance was user-confirmed on 2026-09-29, including the reduced scrolling speed.

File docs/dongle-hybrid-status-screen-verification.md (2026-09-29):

# Corney Dongle Hybrid Status Screen Verification

Date: 2026-09-29

## Scope

The `corney-usb-dongle` custom compositor restores ZMK's standard output, local-battery, and
active-layer widgets at their built-in screen anchors and adds one identity-neutral remote battery
row below the local dongle indicator:

```text
┌────────────────────────┐
│ output          dongle │
│             78%   56%  │
│                        │
│ active layer           │
└────────────────────────┘
```

The two fields retain split-source-index order internally but carry no visible slot number or
left/right claim. Reversing slot assignment after a bond reset therefore does not change the user
meaning. Available values render as bounded `N%`; unavailable values render as `--`.

## Data and presentation boundaries

- ZMK's standard widgets exclusively own output/endpoint state, local dongle battery/USB state, and
  the highest active layer.
- The Corney listener subscribes only to `zmk_peripheral_battery_state_changed` and initializes from
  both retained split battery levels.
- The auxiliary BAS proxy remains disabled. Remote values remain display-local and do not change
  Keyboard Helper capabilities or the dongle's standard Battery Service meaning.
- Pinned ZMK v0.3.0 reports remote disconnect as level zero, so both disconnect and a genuine remote
  `0%` render as `--`.
- The standard local battery widget's lightning/power symbol indicates USB presence; it is not
  evidence that an optional dongle battery is installed or charging.
- The remote row uses Montserrat 12 in a 65-pixel right-aligned area at `y=20..34`. The unkerned
  pinned-font upper bound for `100% 100%` is 65 pixels. The stock top region uses Montserrat 16 with
  an 18-pixel line height, and the bottom layer region uses the 15-pixel small font.

## Automated verification

- [x] Portable host tests cover initial `-- --`, independent updates, bounded values,
  disconnect-zero handling, reversed slot arrival, and `100% 100%`.
- [x] `tests/verify_dongle_display_layout.py` derives glyph advances and line heights from the pinned
  Montserrat sources and verifies the remote row's horizontal and vertical bounds.
- [x] All four native ZMK integration fixtures pass: combo wrapper ordinary/overlap, both-half event
  sources, and input-split pointing/disconnect cleanup.
- [x] All five `nice_nano_v2` release targets build on ZMK commit
  `edf5c0814fd3ea202e43aad2d68fd32e882a518c` (v0.3.0 pin).
- [x] Generated configuration/devicetree verification passes for every target. Only the dongle
  selects the custom compositor, three standard widgets, Montserrat 12/16, and remote battery
  fetching; built-in status and auxiliary BAS proxy remain disabled.
- [x] The direct central, both peripherals, and settings-reset UF2 hashes exactly match the accepted
  preceding battery-screen release.

## Resource change

| Dongle build | FLASH | RAM | UF2 size |
| --- | ---: | ---: | ---: |
| Accepted compact battery screen | 328,564 B | 68,436 B | 657,408 B |
| Hybrid stock-geometry screen | 345,860 B | 68,612 B | 692,224 B |
| Change | +17,296 B | +176 B | +34,816 B |

The hybrid build uses 42.65% of the 792 KiB application flash region and 26.17% of the 256 KiB RAM
region. Relative to the earlier built-in OLED screen it adds 1,888 B FLASH, 160 B RAM, and 4,096 B
of UF2 output while also presenting both remote levels.

## Candidate artifacts

Candidate UF2 files and matching generated `.config` and `zephyr.dts` evidence are stored under
`.artifacts/refine-corney-dongle-status-screen/`.

| Artifact | Size | SHA-256 |
| --- | ---: | --- |
| `corney-left-enhanced.uf2` | 496128 bytes | `7aba0ccd18874ecdf3829aa3a69ed6db863d40a87026ecf3969bad7ef5ce696c` |
| `corney-left-peripheral.uf2` | 355840 bytes | `51069e75b64495508b1ecaff860dee4f62a85456fa7d382ec870c45f81f2396b` |
| `corney-right.uf2` | 355840 bytes | `f7b7a74931fbe5ddcad91d0888dd13a3f5954c8e8d1eb1066bdf61b1280a6185` |
| `corney-usb-dongle.uf2` | 692224 bytes | `0eee7cc882c368aa87ac47aa947d5561093a931f55f81ae276ecb1ac3e04c932` |
| `settings-reset.uf2` | 92672 bytes | `fd3072a56b359a56b08ad0c010b77ebe516846fc59ca21aa5c1059518a082d60` |

## Flash and rollback

Flash only
`.artifacts/refine-corney-dongle-status-screen/corney-usb-dongle.uf2`. Existing half images and BLE
bonds remain compatible and should not be replaced or reset.

If rollback is required, flash
`.artifacts/show-corney-battery-levels-on-dongle/corney-usb-dongle.uf2`. No half reflash is required.

## Physical acceptance

- [x] Confirm the output indicator at upper left, local battery at upper right, unlabeled remote pair
  beneath it, and active layer at lower left are legible and do not visibly overlap.
- [x] Change active layers and endpoint state and confirm the standard widgets update independently.
- [x] Power-cycle each half independently and confirm one field changes to `--` and later recovers
  while the other remains available.
- [x] Confirm idle blanking/wake, USB HID, keys from both halves, available pointing paths,
  disconnect cleanup, and Keyboard Helper retain their accepted behavior.
- [x] Rollback was not required because physical acceptance passed; the documented dongle-only
  rollback artifact remains available.

Physical acceptance was user-confirmed on 2026-09-29. The hybrid screen was reported to look good,
and no layout, input, reconnect, wake, or integration regression was reported.

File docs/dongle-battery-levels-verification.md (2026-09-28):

# Corney Dongle Battery Levels Verification

Date: 2026-09-28

## Scope

The `corney-usb-dongle` custom status screen presents three independent power sources on the
existing 128x64 SSD1306:

```text
Half 1   78%
Half 2   64%
Dongle   42% USB
```

`Half 1` and `Half 2` are ZMK peripheral source slots, not permanent left/right identities. The
labels therefore remain valid if the halves bond in another order. A disconnected or not-yet-seen
slot is shown as `--`.

Only the dongle firmware changes. The direct central, both peripheral images, and settings-reset
remain byte-identical to the accepted `add-corney-dongle-oled` artifacts. The existing SSD1306
devicetree, orientation, idle blanking, and keyboard-activity wake configuration are unchanged.

## Data boundaries and limitations

- The dongle fetches Battery Service values from both split peripherals with
  `CONFIG_ZMK_SPLIT_BLE_CENTRAL_BATTERY_LEVEL_FETCHING`.
- The auxiliary BAS proxy remains disabled. Battery values are display-local and do not add a
  Keyboard Helper capability or event.
- In pinned ZMK v0.3.0, a peripheral disconnect is reported with level zero. The display therefore
  treats remote `0%` as unavailable and shows `--`; a genuinely empty remote battery cannot be
  distinguished from a disconnected one.
- `Dongle` uses the local ZMK Battery Service state. `USB` means USB power is present and does not
  claim that a battery is charging. `BAT` means USB power is absent.
- Until a battery is installed on the dongle, accuracy of its battery-backed percentage remains a
  deferred physical check.

## Automated verification

- [x] Portable host tests cover initial unavailable slots, independent updates, bounds,
  disconnect-zero handling, local level changes, and USB/BAT formatting.
- [x] Native ZMK integration tests pass for combo delegation, both-half events, input-split
  pointing, and disconnect cleanup.
- [x] All five `nice_nano_v2` release targets build on ZMK commit
  `edf5c0814fd3ea202e43aad2d68fd32e882a518c` (v0.3.0 pin).
- [x] Generated configurations and devicetrees pass `tests/verify_cirque_build.py` for every target.
- [x] Only the dongle selects the custom screen and two-slot battery fetching. The built-in status
  screen and auxiliary BAS proxy are disabled, and the other four targets contain none of the new
  screen code.

## Resource change

| Dongle build | FLASH | RAM | UF2 size |
| --- | ---: | ---: | ---: |
| Accepted built-in OLED screen | 343,972 B | 68,452 B | 688,128 B |
| Custom battery screen | 328,564 B | 68,436 B | 657,408 B |
| Change | -15,408 B | -16 B | -30,720 B |

The custom build uses 40.51% of the 792 KiB application flash region and 26.11% of the 256 KiB
RAM region.

## Candidate artifacts

Candidate UF2 files and matching generated `.config` and `zephyr.dts` evidence are stored under
`.artifacts/show-corney-battery-levels-on-dongle/`.

| Artifact | Size | SHA-256 |
| --- | ---: | --- |
| `corney-left-enhanced.uf2` | 496128 bytes | `7aba0ccd18874ecdf3829aa3a69ed6db863d40a87026ecf3969bad7ef5ce696c` |
| `corney-left-peripheral.uf2` | 355840 bytes | `51069e75b64495508b1ecaff860dee4f62a85456fa7d382ec870c45f81f2396b` |
| `corney-right.uf2` | 355840 bytes | `f7b7a74931fbe5ddcad91d0888dd13a3f5954c8e8d1eb1066bdf61b1280a6185` |
| `corney-usb-dongle.uf2` | 657408 bytes | `675c8a22f8a7ce96112b784710e4675035262cc9e60d813c6a68d91fafdf674a` |
| `settings-reset.uf2` | 92672 bytes | `fd3072a56b359a56b08ad0c010b77ebe516846fc59ca21aa5c1059518a082d60` |

The four non-dongle hashes exactly match the accepted preceding OLED candidate. Only
`corney-usb-dongle` changed.

## Flash and rollback

For physical acceptance, flash only the new `corney-usb-dongle.uf2`. Existing half images and BLE
bonds should remain usable; no half reflash or re-pairing is expected.

If rollback is needed, flash
`.artifacts/add-corney-dongle-oled/corney-usb-dongle.uf2` on the dongle. The halves do not need to
be reflashed.

## Physical acceptance

- [x] Confirmed legible `Half 1`, `Half 2`, and `Dongle` values plus the USB marker.
- [x] Power-cycled each half independently and confirmed `--` then recovered level without breaking
  keys, pointing, USB HID, or disconnect cleanup.
- [x] Confirmed display idle blanking/wake and unchanged Keyboard Helper behavior.
- [x] Accepted dongle local data flow and USB indication; percentage accuracy remains pending until
  a dongle battery is installed.

Physical acceptance was user-confirmed on 2026-09-28. No connection or update-delay limitation was
reported. The pending dongle battery-backed percentage is an explicitly accepted hardware gap, not
a failure of the current USB-powered configuration.

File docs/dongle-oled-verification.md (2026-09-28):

# Corney USB Dongle OLED Verification

Date: 2026-09-28

## Scope

`corney-usb-dongle` now selects one four-wire 128x64 SSD1306 at I2C address `0x3c` and renders
ZMK's built-in status screen. The display is isolated to the USB-powered dongle. The direct central,
left peripheral, right peripheral, and settings-reset targets remain display-free; their accepted
matrix, optional Cirque, split, pointing, and Keyboard Helper roles do not change.

The configuration was adapted from the hardware-tested `my-zmk-test` overlay. Corney's pinned
Zephyr binding supports the geometry, orientation, precharge, and 100 ms ready delay used here but
does not support the newer `use-internal-iref` property, so that property is intentionally absent.

## Wiring

Use a 3.3 V-compatible four-pin I2C SSD1306 module:

| SSD1306 pin | Dongle nice!nano v2 / Pro Micro pin |
| --- | --- |
| `VCC` | `3V3` |
| `GND` | `GND` |
| `SDA` | `D2` / `P0.17` |
| `SCL` | `D3` / `P0.20` |

The expected address is `0x3c`. Do not use `RAW` or 5 V unless the exact module has separately been
verified to accept that supply. Neither keyboard half is rewired for this change.

## Automated verification

- [x] Portable host tests pass, including the exact five-artifact release matrix.
- [x] Native ZMK integration tests pass for combo delegation, both-half events, and input-split
  pointing/disconnect recovery.
- [x] All five `nice_nano_v2` release targets build on pinned ZMK v0.3.0.
- [x] Generated configurations and devicetrees pass `tests/verify_cirque_build.py` for every target.
- [x] The dongle resolves I2C, SSD1306, Zephyr/ZMK display support, built-in status screen, and
  one-bit LVGL output while retaining USB, BLE split central, both pointing proxies, disconnect
  safety, and the complete Keyboard Helper extension.
- [x] The dongle generated devicetree selects exactly one 128x64 SSD1306 at `0x3c`, contains no
  physical Cirque or GPIO matrix, and the other four targets contain no dongle display.

## Resource change

Linker memory usage and UF2 size are compared with the accepted display-free dongle whose UF2 hash
is `d8577d60330acd78af3eca2b65f170738285cfd2bf35ec7b99f1e02ebd1144f0`.

| Dongle build | FLASH | RAM | UF2 size |
| --- | ---: | ---: | ---: |
| Display-free baseline | 242,704 B | 62,132 B | 485,888 B |
| Built-in OLED status screen | 343,972 B | 68,452 B | 688,128 B |
| Change | +101,268 B | +6,320 B | +202,240 B |

The display-enabled build uses 42.41% of the 792 KiB application flash region and 26.11% of the
256 KiB RAM region.

## Candidate artifacts

Candidate UF2 files and matching generated `.config` and `zephyr.dts` evidence are stored under
`.artifacts/add-corney-dongle-oled/`.

| Artifact | Size | SHA-256 |
| --- | ---: | --- |
| `corney-left-enhanced.uf2` | 496128 bytes | `7aba0ccd18874ecdf3829aa3a69ed6db863d40a87026ecf3969bad7ef5ce696c` |
| `corney-left-peripheral.uf2` | 355840 bytes | `51069e75b64495508b1ecaff860dee4f62a85456fa7d382ec870c45f81f2396b` |
| `corney-right.uf2` | 355840 bytes | `f7b7a74931fbe5ddcad91d0888dd13a3f5954c8e8d1eb1066bdf61b1280a6185` |
| `corney-usb-dongle.uf2` | 688128 bytes | `c5e6b8606ff9a921da79c93d1a68e95cdd628b0ed9faf7e98dc5f0cf0ee877ad` |
| `settings-reset.uf2` | 92672 bytes | `fd3072a56b359a56b08ad0c010b77ebe516846fc59ca21aa5c1059518a082d60` |

The four non-dongle artifacts are byte-identical to the accepted preceding dongle-topology
candidate. Only `corney-usb-dongle` changed.

## Physical acceptance

- [x] Wired the compatible SSD1306 and flashed only the new `corney-usb-dongle` candidate.
- [x] Confirmed legible built-in ZMK status content in the expected orientation after boot.
- [x] Confirmed idle blanking and wake after keyboard activity.
- [x] Confirmed USB enumeration, typing from both halves, available pointing paths, Keyboard Helper,
  and independent half reconnect while the display is active.
- [x] The candidate passed, so rollback was not required. The preceding display-free dongle UF2
  remains available without reflashing either half.

Physical acceptance was user-confirmed on 2026-09-28: all requested manual tests passed and the
display looked as expected. The display changes only the central image; neither peripheral was
reflashed for this check.

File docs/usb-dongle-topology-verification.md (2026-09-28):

# Corney USB Dongle Topology Verification

Date: 2026-09-28

## Firmware roles

- `corney-left-enhanced`: existing direct central with local left Cirque, right input-split proxy,
  USB/BLE HID, and Keyboard Helper BLE service.
- `corney-left-peripheral`: BLE left half with matrix scanning and optional Cirque forwarded through
  input-split register `1`.
- `corney-right`: universal BLE right half with optional Cirque forwarded through the retained
  input-split register `0`.
- `corney-usb-dongle`: keyless central with two BLE peripheral slots, two pointing proxies, USB
  HID, and Keyboard Helper BLE service.
- `settings-reset`: bond-reset utility.

Both central targets use the default device name `Corney`. ZMK Studio remains disabled. Keyboard
Helper continues to use encrypted BLE GATT even while the dongle sends HID to the computer over
USB. The dongle does not report the battery level of either half.

## Entering dongle mode

Changing the central invalidates the existing split bonds. Do not try to reuse bonds from direct
mode.

1. Flash `settings-reset` to the future dongle, left half, and right half; allow each device to boot.
2. Flash `corney-usb-dongle` to the dongle.
3. Flash `corney-left-peripheral` to the left half.
4. Flash the unchanged `corney-right` artifact to the right half.
5. Power the dongle from the computer over USB and power both halves. Allow both split bonds to be
   established before testing.

## Returning to direct mode

1. Flash `settings-reset` to the left and right halves; reset the dongle too before its next use.
2. Flash `corney-left-enhanced` to the left half.
3. Flash the same `corney-right` artifact to the right half.
4. Pair the `Corney` central to the intended BLE hosts again.

## Automated acceptance

- [x] Host tests pass, including exact five-artifact matrix checks.
- [x] Native ZMK integration tests pass, including two input-split registers, independent retained
  button state, bounded cleanup, and continued post-cleanup input.
- [x] All five `nice_nano_v2` targets build on pinned ZMK `v0.3.0`.
- [x] Generated configurations and devicetrees pass `tests/verify_cirque_build.py`.
- [x] Candidate UF2 files, hashes, and generated configuration evidence are retained.

The candidate files are stored under `.artifacts/add-corney-usb-dongle-topology/`; matching
resolved `.config` and `zephyr.dts` files are retained in its `config/` and `devicetree/`
subdirectories.

| Artifact | Size | SHA-256 |
| --- | ---: | --- |
| `corney-left-enhanced.uf2` | 496128 bytes | `7aba0ccd18874ecdf3829aa3a69ed6db863d40a87026ecf3969bad7ef5ce696c` |
| `corney-left-peripheral.uf2` | 355840 bytes | `51069e75b64495508b1ecaff860dee4f62a85456fa7d382ec870c45f81f2396b` |
| `corney-right.uf2` | 355840 bytes | `f7b7a74931fbe5ddcad91d0888dd13a3f5954c8e8d1eb1066bdf61b1280a6185` |
| `corney-usb-dongle.uf2` | 485888 bytes | `d8577d60330acd78af3eca2b65f170738285cfd2bf35ec7b99f1e02ebd1144f0` |
| `settings-reset.uf2` | 92672 bytes | `fd3072a56b359a56b08ad0c010b77ebe516846fc59ca21aa5c1059518a082d60` |

## Physical acceptance

- [x] Keys, combos, and layers from each half work independently and together over dongle USB HID.
- [x] Each half can be power-cycled without disabling the other, reconnects, and leaves no stuck
  key or pointing button.
- [x] Every available left/right Cirque path is checked for movement, orientation, tap, supported
  wheel input, key-driven idle resume, reconnect, and sensorless operation.
- [x] An encrypted BLE client observes Keyboard Helper capabilities and representative key, combo,
  layer, reconnect, and two-subscriber behavior while USB HID is active.
- [ ] The direct `corney-left-enhanced` plus `corney-right` topology still passes its accepted
  no-dongle regression checks after resetting bonds. This check was explicitly deferred by the
  user on 2026-09-28 to avoid reflashing the currently accepted dongle topology.
- [x] Simultaneous operation of two installed compatible Cirque sensors is explicitly recorded as
  **pending**, not passed: a two-sensor physical assembly is not currently available.

On 2026-09-28 the user flashed all three dongle-topology devices and confirmed operation of the
dongle and all existing functions. The direct-topology rollback check remains outstanding and was
explicitly deferred because it requires resetting bonds and reflashing the left half from
`corney-left-peripheral` to `corney-left-enhanced` (followed by re-pairing); the current confirmation
covered the three-device dongle topology.

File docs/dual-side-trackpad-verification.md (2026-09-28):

# Dual-side Cirque Trackpad Verification

Date: 2026-09-28

## Firmware topology

The release pair supports an optional Cirque Pinnacle at address `0x2a` on either or both halves:

- `corney-left-enhanced` polls a local sensor with `invert-x` and sends its events through a
  dedicated local ZMK input listener. It also retains the separate input-split proxy listener for
  the right sensor.
- `corney-right` retains the accepted polling device, `invert-y` orientation, and input-split
  endpoint.
- `settings-reset` contains neither Cirque device nor pointing listener.

The left/central release build uses the default Bluetooth name `Corney`; no
`CONFIG_ZMK_KEYBOARD_NAME` override was supplied. ZMK Studio remains disabled and the complete
Keyboard Helper capability set remains enabled.

## Automated verification

- `tests/run-host-tests.sh`: pass, including packet, wheel, button, per-side orientation, BLE
  metadata, and exact release-matrix checks.
- `tests/run-zmk-integration-tests.sh`: pass for all four fixtures, including input-split movement,
  wheel, button, disconnect release, reconnect, and synchronization events.
- `tests/verify_cirque_build.py`: pass for generated `corney_left`, `corney_right`, and
  `settings_reset` configurations and devicetrees.
- All three `nice_nano_v2` release targets build successfully without adding an artifact.

## Central resource change

Relative to the accepted Studio-free central from `remove-zmk-studio-from-corney-firmware`:

| Central build | FLASH | RAM | UF2 size |
| --- | ---: | ---: | ---: |
| Studio-free, right sensor only | 243,864 B | 59,836 B | 487,936 B |
| Optional left and right sensors | 247,916 B | 60,036 B | 496,128 B |
| Change | +4,052 B | +200 B | +8,192 B |

## Candidate artifacts

The default-name release candidates are stored under
`.artifacts/restore-corney-left-trackpad/`:

| Artifact | Size | SHA-256 |
| --- | ---: | --- |
| `corney-left-enhanced.uf2` | 496128 bytes | `fedd853f9ae453237221466a126c01cd26dcd3ffa5e9861498a8bbda25adb838` |
| `corney-right.uf2` | 355840 bytes | `f7b7a74931fbe5ddcad91d0888dd13a3f5954c8e8d1eb1066bdf61b1280a6185` |
| `settings-reset.uf2` | 92672 bytes | `fd3072a56b359a56b08ad0c010b77ebe516846fc59ca21aa5c1059518a082d60` |

The right and settings-reset images are byte-identical to the preceding accepted release; only the
left central changed.

## Physical acceptance

User-confirmed on 2026-09-28:

- On the available left-sensor keyboard, X/Y direction, scrolling, primary tap, USB and BLE
  pointing, key-driven idle resume, ordinary typing, combos, layers, and Keyboard Helper work as
  expected.
- The retained right-sensor path, split reconnect, right-local-key resume, right-source release,
  and sensorless behavior remain confirmed by the preceding right-peripheral acceptance and were
  reported as working as expected for the remaining scenarios.
- No new battery, responsiveness, or throughput limitation was observed during the reported tests.

A keyboard with physical sensors installed on both halves was not available. Dual-sensor
coexistence and simultaneous relative input on one split pair therefore remain unverified hardware
scenarios even though both generated paths compile together in the central image. This limitation
was explicitly accepted for archiving.

Movement, scrolling, and non-overlapping taps are supported from either sensor. Simultaneously
holding the same logical mouse button from both sensors is outside the accepted contract because
the pinned ZMK input listener does not source-count button ownership; this unsupported gesture was
not physically tested.

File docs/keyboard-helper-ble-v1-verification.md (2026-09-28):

# Keyboard Helper BLE v1 verification record

> Historical evidence: the Studio-enabled central measurements below predate
> `remove-zmk-studio-from-corney-firmware`. The current release central disables ZMK Studio while
> retaining the full Keyboard Helper service; the recorded protocol results remain applicable.

This record intentionally contains no captured typing content, addresses, credentials, or bonding
material.

## Reproducible build evidence

- Date: 2026-08-31
- ZMK revision: `v0.2.1` (`241ff39556b3685c9344c4c22fd9a655af8eb3ba`)
- Original requested board string: `nice_nano@2.0.0` (later found to resolve to the v1 board
  definition on this Zephyr 3.5 baseline; superseded by the corrected v2 artifacts below)
- Protocol: `1.0`
- Host tests: passed
- ZMK native event/combo integration tests: passed
- Position metadata: 42 unique global positions
- Combo metadata: IDs `1..7`, complete and consistent between layout and devicetree

### Hosted CI status

The first GitHub Actions native-test run failed before executing a test because the unanchored
`.gitignore` entry `zmk` also excluded `tests/zmk` from the repository. The rule is now anchored to
the root checkout as `/zmk`, and the integration fixtures are included. The next run reached the
fixtures but invoked `west build` outside the isolated west workspace, so all cases failed before
compilation. The workflow now runs the checkout's test script with `$base_dir` as its working
directory and enables verbose build output. All three cases pass locally in the same
`zmkfirmware/zmk-build-arm:stable` container. The subsequent hosted GitHub Actions rerun completed
successfully, including host tests, native integration tests, and the firmware build matrix.

| Build | Extension configuration | FLASH | RAM | Result |
| --- | --- | ---: | ---: | --- |
| Central legacy | extension disabled | 237,656 B | 59,660 B | pass |
| Central enhanced | release configuration, including ZMK Studio RPC | 268,904 B | 87,538 B | pass |
| Central extension-only | all extension capabilities, ZMK Studio disabled | 240,512 B | 60,276 B | pass |
| Central minimal | extension enabled, optional event sources disabled | 239,392 B | 60,276 B | pass |
| Peripheral/right | no host-facing extension | 172,616 B | 33,884 B | pass |
| Settings reset | utility image | 46,188 B | 11,552 B | pass |

Extension-only versus legacy central delta is 2,856 B FLASH and 616 B RAM. The release-enhanced
image also includes ZMK Studio RPC, so its 31,248 B FLASH and 27,878 B RAM delta is not attributable
to the BLE extension alone. All keyboard variants retain ZMK's standard Battery Service; capability
bit 3 is masked clear, custom event type `0x04` is reserved, and split-central peripheral battery
fetching remains disabled.

### Concurrent-transport platform evidence (2026-09-01)

- The supported central configuration explicitly sets `CONFIG_BT_MAX_CONN=6` and
  `CONFIG_BT_MAX_PAIRED=6`: five ZMK host profiles plus the right split peripheral. The transport
  has a build assertion requiring `CONFIG_BT_MAX_CONN` to cover configured split-central
  peripherals plus at least two host subscribers.
- ZMK `v0.2.1` pins Zephyr `v3.5.0+zmk-fixes`. In that revision, targeted
  `bt_gatt_notify(conn, ...)` checks the selected connection's CCC state and copies notification
  data into a Bluetooth buffer before returning. The worker's per-attempt stack frame therefore
  remains valid without a completion callback; a successful return means the caller-owned bytes
  have already been copied, not that the radio transmission has completed.
- A disconnect callback removes only the matching registry slot and releases its retained
  `bt_conn` reference. Managed CCC restoration after encryption is idempotent, so restoring one
  persisted subscription does not reset another subscriber.
- The retained event history remains 16 entries and stores each encoded live frame once. The
  subscriber registry is fixed at build time from `CONFIG_BT_MAX_CONN`; there is no heap allocation
  and no single-owner compatibility branch.

The concurrent transport was then rebuilt in the same official ZMK container and pinned workspace:

| Post-change build | FLASH | RAM | Delta from pre-change counterpart | Result |
| --- | ---: | ---: | ---: | --- |
| Central enhanced | 270,264 B | 87,906 B | +1,360 B FLASH, +368 B RAM | pass |
| Peripheral/right | 172,616 B | 33,884 B | unchanged | pass |

The resolved central `.config` contains `CONFIG_BT_MAX_CONN=6`,
`CONFIG_BT_MAX_PAIRED=6`, `CONFIG_ZMK_SPLIT_BLE_CENTRAL_PERIPHERALS=1`, and a 16-entry retained
history. The central uses 33.32% of its 792 KiB application FLASH region and 33.53% of its 256 KiB
RAM region. The pinned native ZMK event/combo integration suite also passes with the concurrent
sources.

## ZMK v0.3.0 upgrade evidence (2026-09-05)

- Manifest revision: `v0.3.0` (`edf5c0814fd3ea202e43aad2d68fd32e882a518c`)
- Imported Zephyr revision: `v3.5.0+zmk-fixes` (`dacab4875df72109b96cc8977547a0dc04875bcd`)
- Board: `nice_nano_v2` (legacy Zephyr 3.5 identifier, not HWMv2 syntax)
- Protocol: unchanged at `1.0`
- Formatting and host tests: passed
- ZMK native event/combo integration tests: all three cases passed
- Firmware source adaptations: none required

All targets declared in `build.yaml` were built from the updated west workspace with Zephyr SDK
0.16.8. The Studio-enabled target additionally used an isolated Python 3.12 environment containing
`protobuf`, `grpcio-tools`, and `setuptools<81`; the setuptools upper bound preserves the
`pkg_resources` API used by the pinned nanopb generator.

| Build | Extension configuration | FLASH | RAM | UF2 size | Result |
| --- | --- | ---: | ---: | ---: | --- |
| Central legacy | extension disabled | 238,568 B | 58,620 B | 477,184 B | pass |
| Central enhanced | release configuration, including ZMK Studio RPC | 271,296 B | 86,874 B | 542,720 B | pass |
| Central minimal | extension enabled, optional event sources disabled | 241,112 B | 59,604 B | 482,304 B | pass |
| Peripheral/right | no host-facing extension | 173,320 B | 33,900 B | 347,136 B | pass |
| Settings reset | utility image | 46,188 B | 11,552 B | 92,672 B | pass |

Every corrected artifact resolves `CONFIG_BOARD_NICE_NANO_V2=y`; all normal keyboard images also
resolve `CONFIG_ZMK_BATTERY_NRF_VDDH=y`. The enhanced central resolves
`CONFIG_BT_MAX_CONN=6`, `CONFIG_BT_MAX_PAIRED=6`,
`CONFIG_ZMK_SPLIT_BLE_CENTRAL_PERIPHERALS=1`, `CONFIG_ZMK_STUDIO=y`, and a 16-entry Keyboard
Helper history. This retains five host-profile slots alongside the split peripheral and satisfies
the build assertion reserving capacity for at least two concurrent host subscribers. The
`v0.3.0` update did not change BLE UUIDs, capability bits, frame layouts, keymap metadata, or the
legacy layer-control contract.

### v0.3.0 hardware acceptance status

The initial `v0.3.0` images were flashed to both halves and ordinary keyboard behavior was reported
to work as expected, but BLE Battery Level read 0%. Inspection showed those images had resolved
`nice_nano@2.0.0` to the pin-compatible v1 board definition and selected its absent ADC voltage
divider. The previous 100% reading was also not valid: ZMK `v0.2.1` left the Battery Service's
default value unchanged when the sampled state remained zero, while `v0.3.0` synchronizes zero to
the service. These preliminary images are superseded and are not accepted artifacts.

The corrected `nice_nano_v2` images select the controller's VDDH sensor and passed the full
automated matrix. Matching corrected images were then flashed to both halves and manually accepted:

- ordinary typing, both-half input, split reconnect, configured combos, and layers worked as
  expected;
- pointing movement and scrolling worked over USB and BLE, including profile switching;
- ZMK Studio connected and exposed the keymap;
- an encrypted generic BLE client successfully exercised legacy layer read/write/notify, Keyboard
  Helper discovery and capabilities, stream-start snapshot, representative key/combo/layer events,
  disconnect, and resubscription;
- existing bonds and settings survived the update, so the settings-reset image was not required;
- standard BLE Battery Level reported a plausible nonzero value independently of Keyboard Helper
  telemetry.

This confirms that selecting the v2 VDDH sensor fixes the invalid zero reading and that the accepted
ZMK `v0.3.0` images preserve the required hardware behavior.

## Cirque polling build evidence (2026-09-06)

The left/central shield now contains the I2C-only Cirque Pinnacle polling driver. The sensor is at
address `0x2a`, has no DR connection, and is polled every 8 ms while the central is active. Host
tests cover status filtering, malformed packet rejection, signed relative-axis boundaries, wheel
decoding, explicit X-axis orientation inversion, and primary-button press/hold/release transitions.
The left shield enables X inversion so physical right/left finger movement maps to the same cursor
direction while Y remains unchanged. The existing BLE metadata/transport
host tests and all three native ZMK event/combo integration tests also pass.

Every target declared in `build.yaml` was rebuilt from the pinned ZMK `v0.3.0` workspace:

| Build | FLASH | RAM | UF2 size | Result |
| --- | ---: | ---: | ---: | --- |
| Central legacy | 242,592 B | 58,836 B | 485,376 B | pass |
| Central enhanced with Studio | 275,668 B | 87,162 B | 551,424 B | pass |
| Central minimal | 245,136 B | 59,820 B | 490,496 B | pass |
| Peripheral/right | 173,320 B | 33,900 B | 347,136 B | pass |
| Settings reset | 46,188 B | 11,552 B | 92,672 B | pass |

Generated configuration and devicetree output contain `CONFIG_I2C=y`,
`CONFIG_INPUT_CORNEY_PINNACLE_POLLING=y`, and `glidepoint@2a` only for central targets. The right
and settings-reset artifacts contain none of them. Hardware movement, tap, suspend/resume, and
battery-impact checks remain pending until matching images are flashed.

The first hardware movement check found the installed sensor's X direction reversed while Y was
correct. The rebuilt central images enable the tested `invert-x` transform; same-direction
right/left cursor movement was confirmed after flashing the corrected left image.
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

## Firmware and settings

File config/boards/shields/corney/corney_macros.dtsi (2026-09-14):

// layers
#define DEFAULT 0
#define DEFAULT_LINUX 1
#define DEFAULT_LINUX_SHIFT 2
#define DEFAULT_LINUX_ALT 3
#define DEFAULT_MAC  4
#define DEFAULT_MAC_SHIFT  5
#define DEFAULT_MAC_ALT  6
#define DEFAULT_ANDROID 7
#define RUSSIAN 8
#define RUSSIAN_MAC 9
#define RUSSIAN_MAC_SHIFT 10
#define RUSSIAN_ALT 11
#define RUSSIAN_MAC_ALT 12
#define FUNC 13
#define CHARS 14
#define CHARS_DE 15
#define CHARS_MAC 16
#define CHARS_MAC_RUS 17
#define MOUSE_LAYER 18


/ {
    behaviors {
        kh_combo_esc: kh_combo_esc {
            compatible = "corney,behavior-combo-telemetry";
            #binding-cells = <0>;
            combo-id = <1>;
            key-positions = <1 2>;
            bindings = <&kp ESC>;
        };
        kh_combo_enter: kh_combo_enter {
            compatible = "corney,behavior-combo-telemetry";
            #binding-cells = <0>;
            combo-id = <2>;
            key-positions = <15 16>;
            bindings = <&kp RET>;
        };
        kh_combo_left_enter: kh_combo_left_enter {
            compatible = "corney,behavior-combo-telemetry";
            #binding-cells = <0>;
            combo-id = <3>;
            key-positions = <19 20>;
            bindings = <&kp RET>;
        };
        kh_combo_delete: kh_combo_delete {
            compatible = "corney,behavior-combo-telemetry";
            #binding-cells = <0>;
            combo-id = <4>;
            key-positions = <27 28>;
            bindings = <&kp BSPC>;
        };
        kh_combo_left_delete: kh_combo_left_delete {
            compatible = "corney,behavior-combo-telemetry";
            #binding-cells = <0>;
            combo-id = <5>;
            key-positions = <31 32>;
            bindings = <&kp BSPC>;
        };
        kh_combo_mouse_layer: kh_combo_mouse_layer {
            compatible = "corney,behavior-combo-telemetry";
            #binding-cells = <0>;
            combo-id = <6>;
            key-positions = <40 41>;
            bindings = <&tog MOUSE_LAYER>;
        };
        kh_combo_mouse_layer_left: kh_combo_mouse_layer_left {
            compatible = "corney,behavior-combo-telemetry";
            #binding-cells = <0>;
            combo-id = <7>;
            key-positions = <36 37>;
            bindings = <&tog MOUSE_LAYER>;
        };
    };

    combos {
        compatible = "zmk,combos";
        combo_esc {
            timeout-ms = <50>;
            key-positions = <1 2>;
            bindings = <&kh_combo_esc>;
        };
        combo_enter {
            timeout-ms = <50>;
            key-positions = <15 16>;
            bindings = <&kh_combo_enter>;
        };
        combo_left_enter {
            timeout-ms = <50>;
            key-positions = <19 20>;
            bindings = <&kh_combo_left_enter>;
        };
        combo_delete {
            timeout-ms = <50>;
            key-positions = <27 28>;
            bindings = <&kh_combo_delete>;
        };
        combo_left_delete {
            timeout-ms = <50>;
            key-positions = <31 32>;
            bindings = <&kh_combo_left_delete>;
        };
        combo_mouse_layer {
            timeout-ms = <50>;
            key-positions = <40 41>;
            bindings = <&kh_combo_mouse_layer>;
        };
        combo_mouse_layer_left {
            timeout-ms = <50>;
            key-positions = <36 37>;
            bindings = <&kh_combo_mouse_layer_left>;
        };
    };
};

/ {
    macros {

        to_linux: to_linux {
          compatible = "zmk,behavior-macro";
          #binding-cells = <0>;
          bindings = <&to DEFAULT_LINUX>,
                     <&bt BT_SEL 0>;
        };

        to_mac: to_mac {
          compatible = "zmk,behavior-macro";
          #binding-cells = <0>;
          bindings = <&to DEFAULT_MAC>,
                     <&bt BT_SEL 1>;
        };

        to_mac2: to_mac2 {
          compatible = "zmk,behavior-macro";
          #binding-cells = <0>;
          bindings = <&to DEFAULT_MAC>,
                     <&bt BT_SEL 2>;
        };

        to_mac3: to_mac3 {
          compatible = "zmk,behavior-macro";
          #binding-cells = <0>;
          bindings = <&to DEFAULT_MAC>,
                     <&bt BT_SEL 3>;
        };

        to_android: to_android {
          compatible = "zmk,behavior-macro";
          #binding-cells = <0>;
          bindings = <&to DEFAULT_ANDROID>,
                     <&bt BT_SEL 2>;
        };

        cycle_lang_de: cycle_lang_de {
            compatible = "zmk,behavior-macro";
            #binding-cells = <0>;
            bindings
                = <&to DEFAULT_LINUX>,
                  <&kp CAPS>;
        };

        cycle_android: cycle_android {
            compatible = "zmk,behavior-macro";
            #binding-cells = <0>;
            bindings
                = <&to RUSSIAN>,
                  <&sk LCTRL &kp SPACE>;
        };

        cycle_android_de: cycle_android_de {
            compatible = "zmk,behavior-macro";
            #binding-cells = <0>;
            bindings
                = <&to DEFAULT_ANDROID>,
                  <&sk LCTRL &kp SPACE>;
        };

        cycle_mac_de: cycle_mac_de {
            compatible = "zmk,behavior-macro";
            #binding-cells = <0>;
            bindings
                = <&to DEFAULT_MAC>,
                  <&kp CAPS>;
        };

        cycle_lang_ru: cycle_lang_ru {
            compatible = "zmk,behavior-macro";
            #binding-cells = <0>;
            bindings
                = <&to RUSSIAN>,
                  <&kp CAPS>;
        };

        cycle_mac_ru: cycle_mac_ru {
            compatible = "zmk,behavior-macro";
            #binding-cells = <0>;
            bindings
                = <&to RUSSIAN_MAC>,
                  <&kp CAPS>;
        };

        cycle_lang_en: cycle_lang_en {
            compatible = "zmk,behavior-macro";
            #binding-cells = <0>;
            bindings
                = <&to DEFAULT>,
                  <&kp CAPS>;
        };

        altgr_q_for_at: altgr_q_for_at {
            compatible = "zmk,behavior-macro";
            #binding-cells = <0>;
            bindings = <&sk RALT &kp Q>;
        };
        
        altgr_e: altgr_e {
            compatible = "zmk,behavior-macro";
            #binding-cells = <0>;
            bindings = <&sk RALT &kp L>;
        };

        altgr_l_for_at: altgr_l_for_at {
            compatible = "zmk,behavior-macro";
            #binding-cells = <0>;
            bindings = <&sk RALT &kp L>;
        };
        altgr_MINUS: altgr_MINUS {
            compatible = "zmk,behavior-macro";
            #binding-cells = <0>;
            bindings = <&sk RALT &kp MINUS>;
        };

        altgr_N5: altgr_N5 {
            compatible = "zmk,behavior-macro";
            #binding-cells = <0>;
            bindings = <&sk RALT &kp N5>;
        };

        altgr_N6: altgr_N6 {
            compatible = "zmk,behavior-macro";
            #binding-cells = <0>;
            bindings = <&sk RALT &kp N6>;
        };


        altgr_N7: altgr_N7 {
            compatible = "zmk,behavior-macro";
            #binding-cells = <0>;
            bindings = <&sk RALT &kp N7>;
        };
        
        altgr_shift_N7: altgr_shift_N7 {
            compatible = "zmk,behavior-macro";
            #binding-cells = <0>;
            bindings = <&sk RALT &sk LSHIFT &kp N7>;
        };

        altgr_N8: altgr_N8 {
            compatible = "zmk,behavior-macro";
            #binding-cells = <0>;
            bindings = <&sk RALT &kp N8>;
        };

        altgr_N9: altgr_N9 {
            compatible = "zmk,behavior-macro";
            #binding-cells = <0>;
            bindings = <&sk RALT &kp N9>;
        };

        altgr_N0: altgr_N0 {
            compatible = "zmk,behavior-macro";
            #binding-cells = <0>;
            bindings = <&sk RALT &kp N0>;
        };

        altgr_RBKT: altgr_RBKT
        {
            compatible = "zmk,behavior-macro";
            #binding-cells = <0>;
            bindings = <&sk RALT &kp RBKT>;
        };

        altgr_LT: altgr_LT
        {
            compatible = "zmk,behavior-macro";
            #binding-cells = <0>;
            bindings = <&sk RALT &kp LT>;
        };

        altgr_NUBACK: altgr_NUBACK {
            compatible = "zmk,behavior-macro";
            #binding-cells = <0>;
            bindings = <&sk RALT &kp NON_US_BACKSLASH>;
        };

        altgr_N: altgr_N
        {
            compatible = "zmk,behavior-macro";
            #binding-cells = <0>;
            bindings = <&sk RALT &kp N>;
        };
                
        alt_TAB: altgr_TAB
        {
            compatible = "zmk,behavior-macro";
            #binding-cells = <0>;
            bindings = <&sk RALT &kp TAB>;
        };
        

        //======================================

        shift_LALT: shift_LALT {
            compatible = "zmk,behavior-macro";
            #binding-cells = <0>;
            bindings = <&sk LSHIFT &kp LALT>;
        };
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

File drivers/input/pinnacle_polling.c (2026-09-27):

/*
 * Copyright (c) 2024 The ZMK Contributors
 * Copyright (c) 2026 Maxim Korenyugin
 *
 * SPDX-License-Identifier: MIT
 *
 * Register access and initialization are adapted from
 * https://github.com/petejohanson/cirque-input-module.
 */

#define DT_DRV_COMPAT corney_cirque_pinnacle_polling

#include <errno.h>
#include <stdbool.h>
#include <stdint.h>

#include <zephyr/device.h>
#include <zephyr/devicetree.h>
#include <zephyr/drivers/i2c.h>
#include <zephyr/dt-bindings/input/input-event-codes.h>
#include <zephyr/input/input.h>
#include <zephyr/kernel.h>
#include <zephyr/logging/log.h>
#include <zephyr/pm/device.h>
#include <zephyr/sys/util.h>

#include <corney/pinnacle_packet.h>

LOG_MODULE_REGISTER(corney_pinnacle, CONFIG_INPUT_LOG_LEVEL);

#define PINNACLE_READ_MASK 0xA0U
#define PINNACLE_WRITE_MASK 0x80U

#define PINNACLE_REG_FIRMWARE_ID 0x00U
#define PINNACLE_REG_STATUS1 0x02U
#define PINNACLE_REG_SYS_CONFIG1 0x03U
#define PINNACLE_REG_FEED_CONFIG1 0x04U
#define PINNACLE_REG_FEED_CONFIG2 0x05U
#define PINNACLE_REG_CAL_CONFIG1 0x07U
#define PINNACLE_REG_Z_IDLE 0x0AU
#define PINNACLE_REG_PACKET_BYTE0 0x12U
#define PINNACLE_REG_ERA_VALUE 0x1BU
#define PINNACLE_REG_ERA_ADDR_HIGH 0x1CU
#define PINNACLE_REG_ERA_ADDR_LOW 0x1DU
#define PINNACLE_REG_ERA_CONTROL 0x1EU

#define PINNACLE_FIRMWARE_ID 0x07U
#define PINNACLE_SYS_CONFIG_RESET BIT(0)
#define PINNACLE_SYS_CONFIG_LOW_POWER BIT(2)
#define PINNACLE_FEED_ENABLE BIT(0)
#define PINNACLE_FEED_INTELLIMOUSE BIT(0)
#define PINNACLE_FEED_DISABLE_TAPS BIT(1)
#define PINNACLE_FEED_BUTTON_SCROLL BIT(6)
#define PINNACLE_CALIBRATE BIT(0)
#define PINNACLE_ERA_READ BIT(0)
#define PINNACLE_ERA_WRITE BIT(1)
#define PINNACLE_ERA_ADC_CONFIG 0x0187U
#define PINNACLE_ERA_ADC_MASK 0xC0U

#define PINNACLE_RESET_DELAY_MS 30U
#define PINNACLE_COMMAND_POLL_US 1000U
#define PINNACLE_COMMAND_ATTEMPTS 50U
#define PINNACLE_CALIBRATION_POLL_MS 50U
#define PINNACLE_CALIBRATION_ATTEMPTS 4U
#define PINNACLE_ERROR_LOG_INTERVAL 128U

struct pinnacle_polling_config {
  struct i2c_dt_spec bus;
  uint16_t poll_interval_ms;
  uint8_t sensitivity;
  bool primary_tap_enabled;
  bool invert_x;
  bool invert_y;
  bool sleep_mode_enabled;
};

struct pinnacle_polling_data {
  struct k_work_delayable poll_work;
  const struct device *dev;
  uint32_t consecutive_errors;
  uint8_t buttons;
  bool suspended;
};

static int pinnacle_read(const struct device *dev, uint8_t reg, uint8_t *buffer,
                         size_t size) {
  const struct pinnacle_polling_config *config = dev->config;

  return i2c_burst_read_dt(&config->bus, PINNACLE_READ_MASK | reg, buffer,
                           size);
}

static int pinnacle_write(const struct device *dev, uint8_t reg,
                          uint8_t value) {
  const struct pinnacle_polling_config *config = dev->config;

  return i2c_reg_write_byte_dt(&config->bus, PINNACLE_WRITE_MASK | reg, value);
}

static int pinnacle_wait_for_era(const struct device *dev) {
  uint8_t control;

  for (uint32_t attempt = 0U; attempt < PINNACLE_COMMAND_ATTEMPTS; attempt++) {
    int err =
        pinnacle_read(dev, PINNACLE_REG_ERA_CONTROL, &control, sizeof(control));

    if (err != 0) {
      return err;
    }
    if (control == 0U) {
      return 0;
    }
    k_usleep(PINNACLE_COMMAND_POLL_US);
  }

  return -ETIMEDOUT;
}

static int pinnacle_era_read(const struct device *dev, uint16_t address,
                             uint8_t *value) {
  int err;

  err =
      pinnacle_write(dev, PINNACLE_REG_ERA_ADDR_HIGH, (uint8_t)(address >> 8));
  if (err == 0) {
    err = pinnacle_write(dev, PINNACLE_REG_ERA_ADDR_LOW, (uint8_t)address);
  }
  if (err == 0) {
    err = pinnacle_write(dev, PINNACLE_REG_ERA_CONTROL, PINNACLE_ERA_READ);
  }
  if (err == 0) {
    err = pinnacle_wait_for_era(dev);
  }
  if (err == 0) {
    err = pinnacle_read(dev, PINNACLE_REG_ERA_VALUE, value, sizeof(*value));
  }
  if (err == 0) {
    err = pinnacle_write(dev, PINNACLE_REG_STATUS1, 0U);
  }

  return err;
}

static int pinnacle_era_write(const struct device *dev, uint16_t address,
                              uint8_t value) {
  int err;

  err = pinnacle_write(dev, PINNACLE_REG_ERA_VALUE, value);
  if (err == 0) {
    err = pinnacle_write(dev, PINNACLE_REG_ERA_ADDR_HIGH,
                         (uint8_t)(address >> 8));
  }
  if (err == 0) {
    err = pinnacle_write(dev, PINNACLE_REG_ERA_ADDR_LOW, (uint8_t)address);
  }
  if (err == 0) {
    err = pinnacle_write(dev, PINNACLE_REG_ERA_CONTROL, PINNACLE_ERA_WRITE);
  }
  if (err == 0) {
    err = pinnacle_wait_for_era(dev);
  }
  if (err == 0) {
    err = pinnacle_write(dev, PINNACLE_REG_STATUS1, 0U);
  }

  return err;
}
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

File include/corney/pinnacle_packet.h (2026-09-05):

/*
 * Copyright (c) 2026 Maxim Korenyugin
 *
 * SPDX-License-Identifier: MIT
 */

#pragma once

#include <stdbool.h>
#include <stddef.h>
#include <stdint.h>

#define CORNEY_PINNACLE_RELATIVE_PACKET_SIZE 4U

#define CORNEY_PINNACLE_BUTTON_PRIMARY (1U << 0)
#define CORNEY_PINNACLE_BUTTON_SECONDARY (1U << 1)
#define CORNEY_PINNACLE_BUTTON_AUXILIARY (1U << 2)
#define CORNEY_PINNACLE_BUTTON_MASK                                            \
  (CORNEY_PINNACLE_BUTTON_PRIMARY | CORNEY_PINNACLE_BUTTON_SECONDARY |         \
   CORNEY_PINNACLE_BUTTON_AUXILIARY)

struct corney_pinnacle_relative_sample {
  int16_t x;
  int16_t y;
  int8_t wheel;
  uint8_t buttons;
};

bool corney_pinnacle_status_has_data(uint8_t status);
int corney_pinnacle_decode_relative(
    const uint8_t *packet, size_t packet_size,
    struct corney_pinnacle_relative_sample *sample);
int16_t corney_pinnacle_apply_axis_inversion(int16_t value, bool invert);
uint8_t corney_pinnacle_button_changes(uint8_t previous, uint8_t current);

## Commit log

2025-12-13 add open spcke downgrade board edition
2025-12-13 add first version of board cover
    [board_cover.scad, board_cover.stl]
2025-12-13 add cover
    [board_cover.scad, board_cover.stl]
2025-12-16 tune cover
    [board_cover.scad, board_cover.stl]
2025-12-18 tune the cover
    [board_cover.scad, board_cover.stl]
2025-12-18 make a rounded top
    [board_cover.scad, board_cover.stl]
2025-12-20 body case
    [board_case.scad, board_case.stl, corne-chocoflan-case.stl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]
2025-12-21 add todo list
    [board_case.scad]
2025-12-21 a better case
    [board_case.scad, board_case.stl]
2025-12-21 send key with overlay switch
2025-12-23 rename board and update keymap
2025-12-23 rename board
2025-12-23 rename board files
2025-12-27 add new body
    [ImprovedCorne.FCStd, board_case.scad, body_with_stands.scad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]
2025-12-27 fix one magnet
    [body_with_stands.scad, body_with_stands.stl]
2025-12-28 tuning magnet location
    [body_with_stands.scad]
2025-12-28 body with stands
    [body_with_stands.scad, body_with_stands.stl]
2025-12-28 tune stands
    [body_with_stands.scad, body_with_stands.stl]
2025-12-29 add add stands
    [body_with_stands.scad, body_with_stands.stl]
2025-12-30 save new form
    [board_case.scad, board_case.stl, body_with_stands.scad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]
2025-12-30 add stands
    [board_case.scad, board_case.stl, corne_shape_with_stands.stl]
2025-12-30 tune the case
    [board_case.scad, board_case.stl, body_with_stands.scad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]
2025-12-31 test switch
2026-01-02 add android switch
2026-02-10 case v2
    [board_case.scad, board_case.stl, body_with_stands.scad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]
2026-02-11 improve body
    [body_with_stands.stl, corne_body_models.scad, corne_shape_with_stands.scad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]
2026-02-12 add a new magnet
    [board_case.scad, board_case.stl, body_with_stands.stl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]
2026-02-12 fine tuning
    [board_case.scad, board_case.stl, body_with_stands.stl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]
2026-08-26 add body
    [body_thin.scad]
2026-08-26 add more models
    [board_assembled.scad, board_case.scad, board_cover.scad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]
2026-08-27 add proper legs
    [board_case.scad, body_thin.scad]
2026-08-28 add power cut
    [body_thin.scad]
2026-09-01 allow several streams, add 3d model
    [body_thin.stl]
2026-09-05 add sensor
2026-09-09 add new shape, add stock firmware
    [body_thin.scad]
2026-09-12 add body files
    [board_assembled.scad, board_cover.scad, board_cover.stl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]
2026-09-13 image assets
    [board_cover.scad]
2026-09-14 update keymap
    [board_cover.scad, board_cover.stl, board_cover_reset_button.stl]
2026-09-15 refactor body model
    [_buttons_low_profile.scad, board_assembled.scad, board_cover.scad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]
2026-09-15 add hooks
    [board_cover.scad, body_thin.scad]
2026-09-17 update body
    [board_cover.scad, body_thin.scad]
2026-09-17 render body
    [board_cover.stl, body_thin.scad, body_thin.stl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]
2026-09-20 fix device name
2026-09-20 add windows switcher
2026-09-21 update shape
    [_buttons_low_profile.scad, board_assembled.scad, board_cover.scad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]
2026-09-21 add travel case
    [board_assembled.scad, body_thin.scad, reset_button.scad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]
2026-09-21 new cover
    [internalshape.stl, travel_case_side_by_side.scad]
2026-09-22 simplify body
    [board_assembled.scad, board_cover.scad, body_thin.scad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]
2026-09-27 add right slide sensor
    [_auxiliary.scad, board_assembled.scad, right_touchpad_assembly.scad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]
2026-09-28 restore left sensor
2026-09-30 Add 3D models page
    [board_case.stl, board_cover.stl, board_cover_reset_button.stl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]
2026-09-30 add dongle body
    [dongle_body.scad]
2026-10-02 rename dongle
    [dongle_body.scad, dongle_breadboard.scad, dongle_breadboard_bottom.scad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]
2026-10-02 fix deploy
    [board_case.stl, board_cover.stl, board_cover_reset_button.stl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]
